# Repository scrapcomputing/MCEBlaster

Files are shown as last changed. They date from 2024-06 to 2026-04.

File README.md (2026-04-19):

# MCE Blaster

A versatile standalone MCA/CGA/EGA TTL to VGA adapter based on a raspberry pi Pico.

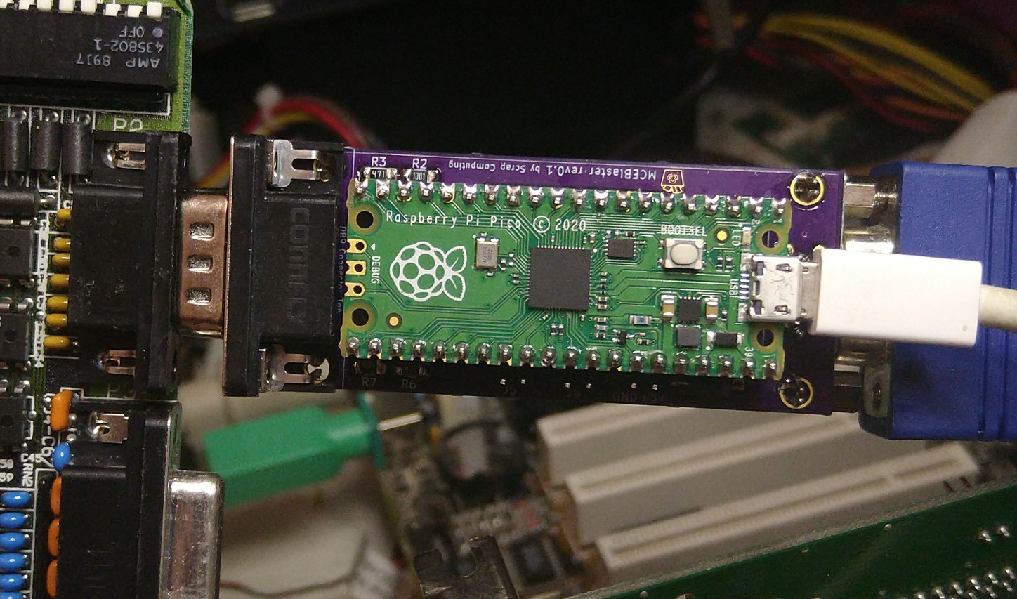
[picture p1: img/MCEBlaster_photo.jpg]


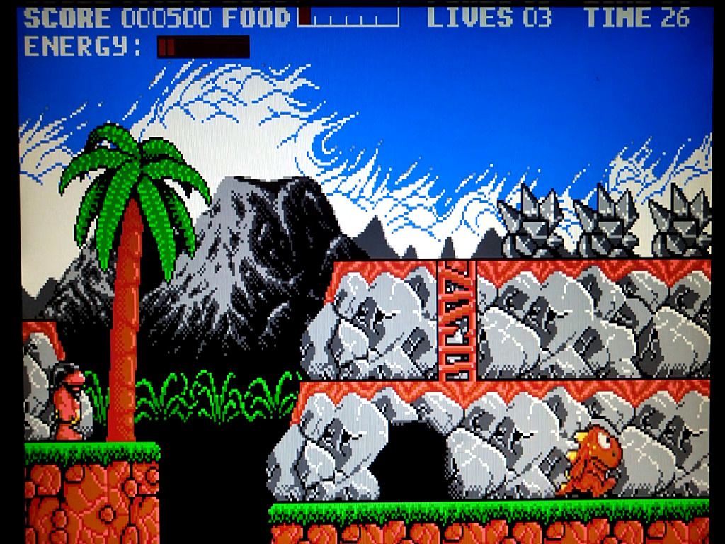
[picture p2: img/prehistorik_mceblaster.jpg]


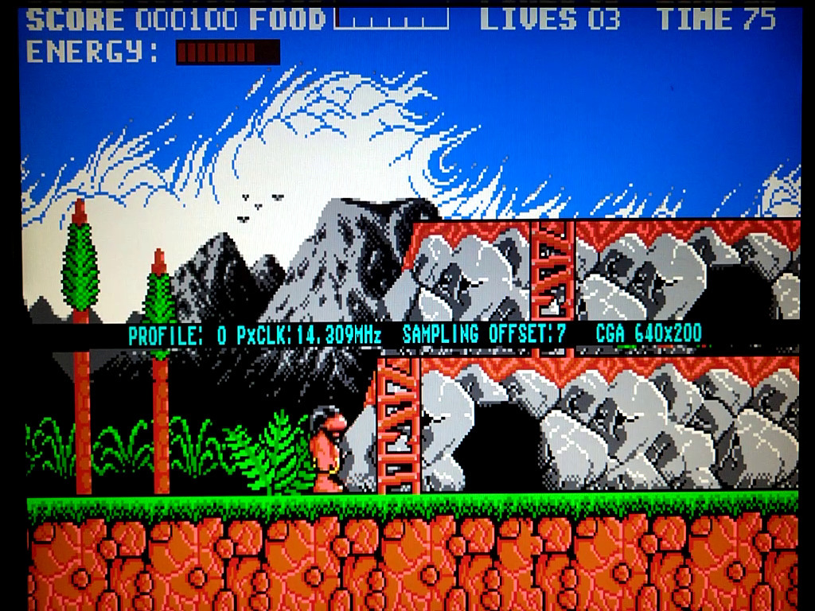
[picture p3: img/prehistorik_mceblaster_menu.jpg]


# Videos
- MCE Blaster video part 3: https://www.youtube.com/watch?v=SX1B-mfE6yk
- MCE Blaster video part 2: https://www.youtube.com/watch?v=Neg1WR7Hz5s
- MCE Blaster video part 1: https://www.youtube.com/watch?v=kgDOiGoxKvE

# What it does
The Pico reads the TTL input video signal, writes the pixels to a buffer and then generates the VGA signal using the pixels from the buffer.

# Features
- No need for a VGA up-scaler or a 15KHz VGA monitor. Works with standard VGA modes.
- Pixel-perfect output:
  - VGA 640x400 for CGA/EGA 320x200,640x200 and 640x350 inputs
  - VGA 800x600 for MDA 720x350
  - VGA 640x480 for vertical resolutions between 200 and 240
- Pixel clock tuning for each mode
- Auto-adjustment functionality that centers the image on screen
- EGA brown color correction
- On-screen menu and messages
- Through-Hole PCB

# Installing the firmware to the Pico (Pico 1 or Pico 2)
- Download firmware (MCEBlaster_pico1.uf2 or MCEBlaster_pico2.uf2): https://github.com/scrapcomputing/MCEBlaster/releases
- Unplug the Pico
- Press and hold the small "BOOTSEL" button on the Pico
- While holding the BOOTSEL button, connect the Pico to your PC with a micro-USB cable
- The Pico should show up as a mass-storage device
- Copy the `MCEBlaster_pico1.uf2` or `MCEBlaster_pico2.uf2` firmware to the drive associated with the Pico
- Safely eject the mass-storage device

# Usage

*NOTE: Controls have changed since version 0.2!*

## Adjusting the pixel clock
- Push the `PIXEL CLOCK` button once, this will enter the pixel adjust mode. This should show text on screen displaying the current pixel clock.
- Coarse adjustment:
  - Push `PIXEL CLOCK` to increment the pixel clock by 10KHz.
  - Push `AUTO ADJUST` to decrement the pixel clock by 10KHz.
- Fine adjustment:
  - Long-push (push until the push registers) `PIXEL CLOCK` to increment the pixel clock by 1 KHz.
  - Long-push (push until the push registers) `AUTO ADJUST` to decrement the pixel clock by 1 KHz.
  - Medium-push (about half a second push and release) `PIXEL CLOCK` to increment the sampling offset and then increment the pixel clock by 1 KHz once we have tried all offsets.
  - Medium-push (about half a second push and release) `AUTO ADJUST` to decrement the sampling offset and then decrement the pixel clock by 1 KHz once we have tried all offsets.
- Exit pixel clock adjust mode by not pushing any buttons for 12 seconds. This saves the settings to flash.

### Sampling Offset (since rev 0.3)
The sampling offset is a fine-tuning knob added in rev 0.3 that shifts TTL sampling to try to avoid sampling the pixels during the transitions (shown as `X`).
In this example, using a sampling offset of 1 will result in a very noisy image because sampling takes place during the pixel transitions.

```
                    _____ _____ _____ _____
TTL Pixels:        X_____X_____X_____X_____X
Sampling offset 0:      |     |     |     |
Sampling offset 1:       |     |     |     |
Sampling offset 2:        |     |     |     |
Sampling offset 3:         |     |     |     |

```

The reason why offsets are needed and a demonstration of how they work can be found in [video part 3](https://www.youtube.com/watch?v=SX1B-mfE6yk).

## Centering the image
- Push the `AUTO ADJUST` button. This works best when the image shown is full from border to border.

## Print TTL Info (since v0.2)
Long-pressing the `PIXEL CLOCK` button will show a screen with information about the TTL signal.
Note: this is not updated in real-time.

You can exit the screen by pushing any button.

## Manually Setting TTL Options (since v0.2)
By default the MCE Blaster will automatically detect the TTL mode by checking the VSync frequency and the VSync Polarity. If these match the standard MDA/CGA/EGA modes used in PCs this will usually work fine.

But since Version 0.2 the MCE Blaster also supports manually setting:
1. The mode (MDA/CGA/EGA),
2. The horizontal and vertical resolution
3. The horizontal and vertical screen offset (on the TTL side)
with the help of an on-screen menu.

The operation is straight forward:
- To enter the menu long-push both buttons for more than a second until the "MANUAL-TTL" menu shows up.
- The single-line menu consists of 4 items that can be modified. The one that can be currently modified is enclosed in square brackets `[<selected>]`. For example:
```
          Currently
          Selected      Horiz Offset  Vertical Offset
            vvv               vvv      vvv
MANUAL-TTL [CGA] 640 x 200 X: AUTO  Y: AUTO
   ^         ^   ^     ^
On/Off  TTL-mode Horiz x Vertical Resolution
```
the currently selected option is `CGA`.
- Change the value of the selected item with a short push of the buttons.
- Cycle through the items by long-pushing the buttons: one will cycle in one direction and the other in the opposite.
- The options are saved to flash when the user stops pushing buttons for 12 seconds.

## Reset to Factory Defaults (since v0.2)
Occasionally the user may save to flash some configuration that makes the MCE Blaster unusable or inoperable.
In this case you can reset to defaults by pressing both buttons while powering on the device.
Upon a successful reset you will see the LED blinking fast for about 2 seconds.
You can release the buttons after that and the MCE Blaster will start with the default settings.

## Profiles (since v0.3 beta13)
The MCE Blaster supports a number of profiles, which helps when swapping video cards.
The settings for one card can be at Profile 0, the settings for another card can be at Profile 1 etc.
The default profile is Profile 0.

Changing profiles is as easy as long-pressing the `AUTO ADJUST` button and cycling through the profiles with either the `AUTO ADJUST` or the `PIXEL CLOCK` button.

Profiles are demonstrated briefly in [video part 3](https://www.youtube.com/watch?v=SX1B-mfE6yk).

# How it works
## Overview
The first core reads the TTL video data (through the level-shifter) from a PIO state-machine and places the pixels onto a buffer in memory.
The second core works completely independently from the first core and reads the pixel from the buffer and feeds them, along with the necessary Horizontal and Vertical Sync signals to a PIO state machine that writes to GPIO outputs.
The output is converted to analogue with the help of a simple R-2R DAC consisting of two resistors.
Feel free to check out the [video part 1](https://www.youtube.com/watch?v=kgDOiGoxKvE) for a visual overview.

## PIO state machines
The PIO state machines are used not only receiving the TTL video data and writing the VGA video data, but also for other helper functions including:
- Detecting no input signal: This checks if the horizontal sync signal is active.
- Detecting the image offset: This counts the black border pixel until a non-black pixel is found across all lines. This count is used for centering the image automatically.
- The EGA PIO state machine also does the Brown pixel fix because the overhead of doing that in a CPU core was too high.

## Sampling clock
The TTL video input is read by a PIO state-machine (one version for each video mode).
But getting it to sample the pixels at the right time requires us adjust the sampling period in a precise way to match the TTL video card's internal pixel clock.
Using the PIO clock divider does not give us a good-enough precision, because the fractional part of the divider is an 8-bit number, meaning that we get precision of ~0.004ns, but what we really need is about 0.001ns.
So what we do is that we have multiple implementations of the state-machine code, each with a different sampling period and we look for the one that has the lowest division error using the PIO's 8-bit divider.
This process is explained in more detail in the [video part 2](https://www.youtube.com/watch?v=Neg1WR7Hz5s).

# PCB
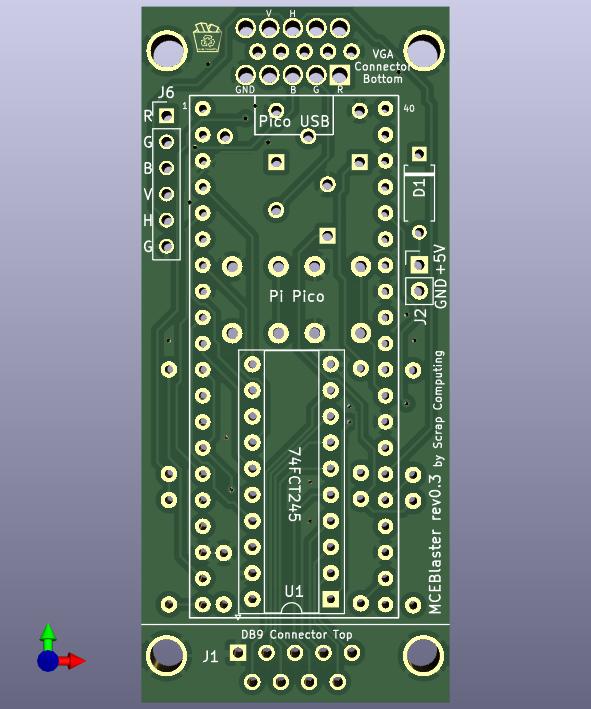
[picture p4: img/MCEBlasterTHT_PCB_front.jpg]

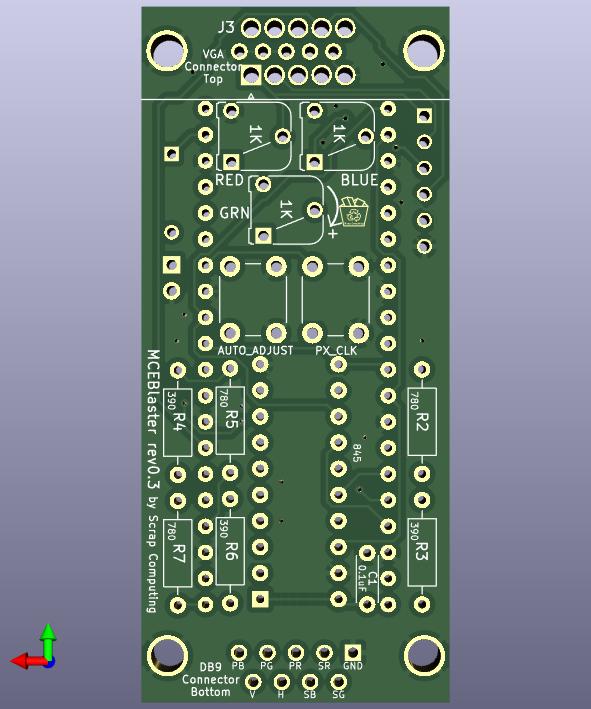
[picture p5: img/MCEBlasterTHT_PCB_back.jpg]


# Schematic

MCE Blaster Schematic

# Bill Of Materials

Download gerbers: https://github.com/scrapcomputing/MCEBlaster/releases

*NOTE: You can still use the latest firmware with old revisions of the PCB, they are fully compatible.*

Reference      | Quantity     | Value                                                                  | Description
---------------|--------------|------------------------------------------------------------------------|------------
N/A            | 3            | 1K Rm065 through-hole linear potentiometer (optional: can be replaced by a wire between 2 pins as shown on PCB and the [photo below](#potentiometers-are-optional) | Adjust R G B VGA signals
C1             | 1            | 0.1uF disk ceramic capacitor                                           | Decoupling capacitor for level-shifter IC
D1             | 1 (optional) | Diode Through-hole (e.g., Schottky 1N5817 or silicon 1N4001)           | For powering the MCE Blaster from the PC (instead of the Pico's micro-USB)
J2             | 1 (optional) | 1x02 through-hole Male PinHeader 2.54mm                                | For alternative external power
J1             | 1            | DB9 Male Horizontal                                                    | For connecting to TTL video card
J3             | 1            | DB15 Female HighDensity Connector (e.g., Kycon K61X-E15S-NJ-VESA, thanks @wrljet) | For connecting to VGA monitor
R3 R4 R6       | 3            | 390 Ohm Through-hole resistor 1% (alternatively 470 Ohm)               | For VGA signal DAC
R2 R5 R7       | 3            | 780 Ohm Through-hole resistor 1% (alternatively 1K Ohm)                | For VGA signal DAC
SW1,SW2        | 2            | 6mm Through-hole push button                                           | Auto-adjust and pixel-clock buttons
U1             | 1            | 74LVC245A DIP-20 (e.g., SN74LVC245AN) (+ optional socket)              | Level-shifter IC (NOTE: in the video I am using an 74HCT245 which turns out operates [out of spec](https://github.com/scrapcomputing/MCEBlaster/issues/31))
U2             | 1            | RaspberryPi Pico (or Pico 2)                                           | Pi Pico (or Pico 2)
N/A (for Pico) | 2            | 1x20 female through-hole pin-header 2.54mm pitch                       | PCB Pico headers
N/A (for Pico) | 2            | 1x20 male through-hole pin-header 2.54mm pitch                         | Headers for the Pico

## Potentiometers are optional.

They can be replaced by a wire as shown in the photo:

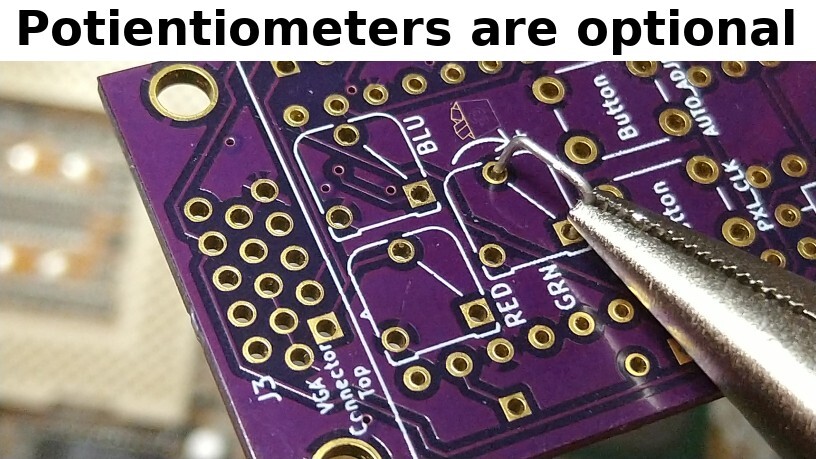
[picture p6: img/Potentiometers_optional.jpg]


# Build instructions (for developers)
## Requirements:
- C++17 cross compiler (see instructions in https://github.com/raspberrypi/pico-sdk)
- Pico-SDK 2.2.0 or later (https://github.com/raspberrypi/pico-sdk)
- cmake 3.13 or later

## Build for Pico (rp2040) or Pico 2 (rp2350)
```
$ cd firmware && mkdir build && cd build
$ cmake -DPICO_BOARD=<pico|pico2> -DCMAKE_BUILD_TYPE=Release -DPICO_FREQ=270000 -DPICO_SDK_PATH=<path-to-pico-sdk> ../src/
$ make -j
```

# Resources:
- https://minuszerodegrees.net/mda_cga_ega/mda_cga_ega.htm
- https://en.wikipedia.org/wiki/IBM_Monochrome_Display_Adapter
- https://en.wikipedia.org/wiki/Enhanced_Graphics_Adapter
- https://en.wikipedia.org/wiki/Color_Graphics_Adapter
- https://en.wikipedia.org/wiki/VGA_connector

# Similar Projects
- Necroware's [mce-adapter](https://github.com/necroware/mce-adapter)
- [RGBtoHDMI](https://github.com/hoglet67/RGBtoHDMI/wiki)

# Change Log
- Rev 0.1: Initial release.
- Rev 0.2: Major redesign. Manual TTL, menus show live background
- Rev 0.3: Better adjustment of pixel clock with sampling offset, support for Pico 2, and fix colors in some monitors

# License
The project is GPLv2.

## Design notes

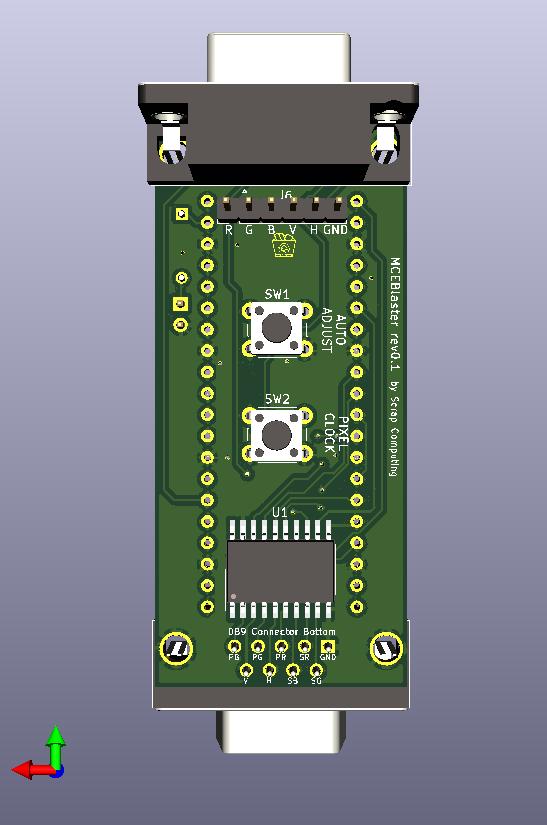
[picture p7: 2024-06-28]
img/MCEBlaster_PCB_back.jpg

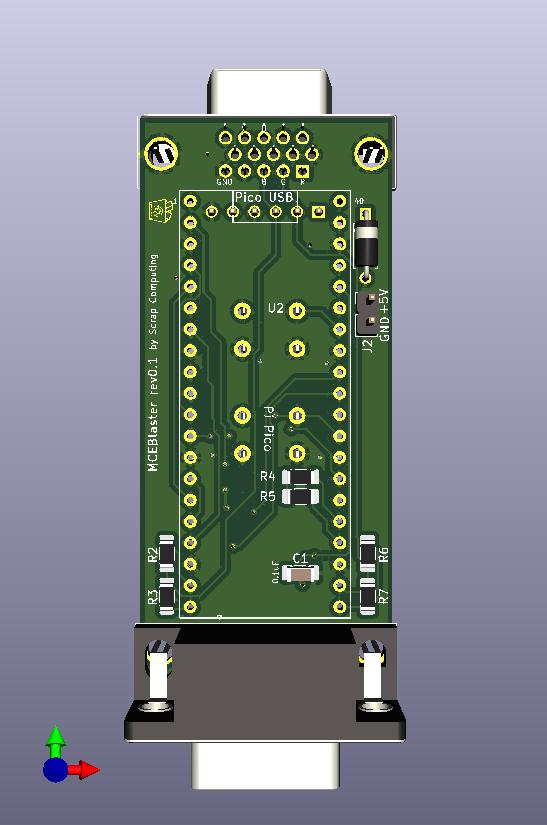
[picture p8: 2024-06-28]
img/MCEBlaster_PCB_front.jpg

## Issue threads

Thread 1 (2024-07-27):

cant find email so I upload boardview for ASUS P5A-B in one of your github projects :) its almost same board, just AT form factor

raszpl, 2024-07-27:
cant find email, uploading here  https://www.youtube.com/watch?v=MigVZLc_Mgw
[ASUS P5a-b_1.05.7z.zip](https://github.com/user-attachments/files/16401720/ASUS.P5a-b_1.05.7z.zip)

HIP is in upper right corner U15, SS controlled by Q11 'VCC2DET'. this signal also goes near the W83781G to either:
-74 series logic chips
-ASUS "Asic"

Asus AS something something 256 is afaik just a bunch of logic gates
EDIT: my own vogons post: https://www.vogons.org/viewtopic.php?p=1120994#p1120994

scrapcomputing, 2024-07-27:
Thanks!

ImprovedTube, 2024-07-29:
you good? @raszpl  will give all my retro computing parts for youtube extension fixes.

Closed 2024-07-27.

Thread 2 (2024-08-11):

Add mode for Apricot XI PC

stevenhoefel, 2024-08-11:
The Apricot XI PC provides an MDA-like display with 800x200 pixels at 15.798khz H and 71.9 V.
I've managed to compile and build the project. I then attempted to manipulate the existing MDA mode to these settings, but I can't stop the Pico from freezing up. I also don't have a proper debugging setup and using USB serial isn't a good method.

Any chance you could provide some guidance on how to add this archaic display mode?

Thank you!

stevenhoefel, 2024-08-11:
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

scrapcomputing, 2024-08-11:
Hi,

For the 800x200 monochrome mode I would change the MDA_720x350@50 entry in TimingsVGA.h (at least for now). Make sure the `F`, `Vis` and `B` fields are multiples of 4, otherwise the Pico will freeze.

From the figure you posted above, I guess the pixel clock is 15MHz, and H sync polarity is positive and V sync polarity is negative.

Something like this may be a good start, though I have not adjusted the porch sizes (please do so if needed and remember they should be multiples of 4, though I don't think they are super critical):
` {16, 800+XB, 20,   126, 20, 200,  4, 16,  Pos,  Neg, 15798, 50, 15000000, 1},`

I think that updating this line shouldn't cause the Pico to freeze and should display something.

Oh btw, don't change the DisplayBuffer's `Buffer` dimensions, 800 monochrome should fit fine, as we are storing 2 pixels per byte horizontally. If you increase the size, the Pico will run out of memory and will freeze.

Debugging is tricky but can be done via USB. You can use `-DDBGPRINT=on` in cmake which turns on some basic debugging. If you have configured the `TimingsVGA.h` correctly then you should be seeing messages like "Updating Buff.Mode=" that match your modified MDA mode.
Otherwise you may be seeing messages like "Could not match Polarity"

 The issue is that printing things via USB can mess up with the timings and you get a noisy image on the VGA, but works all right as long as you don't print too often. I usually print stuff in TTLReader.cpp in `runForEver()`, see commented out lines towards the bottom.

After you get it to show things, you may need some vertical pixel doubling, like in 640x200 EGA mode, similarly to how it's done in VGAWriter.cpp: `DrawLineVSyncHigh4x1(Line/2)` instead of `Line`.

I hope this helps, feel free to reach out again if you run into issues.

stevenhoefel, 2024-08-11:
After a lot of tinkering, the best I could produce was a pretty-good image hanging off the top-right of the screen.

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

It wouldn't work by amending the MDA line... instead I had to amend the EGA 640x200 which makes me think there's other calculations going on for MDA that don't apply to EGA. The line that produced an image was:

  /*EGA_640x200@60:*/ {36,  720+XB, 20,   56, 32,  200, 56, 16,  Pos,  Pos, 15798, 72, 15798000, 1},

Note the 72hz for the Vertical Frequency and Positive V Sync. Otherwise the code reported no matching configuration.
From here, should I just adjust the borders/offers to center this EGA picture? Or should I work harder to get the MDA method to match?

I'll tinker more again tomorrow and review how the code paths for MDA and EGA differ...

Attempting to use the row above in the MDA slot just causes a clear black screen with no image data present at all.

scrapcomputing, 2024-08-11:
Ah nice, you got some image :D

Well the buffer for EGA/CGA is only 640 pixels wide, so it won't fit 800 pixels unless you make the buffer wider but shorter, but in that case you won't be able to switch to EGA/CGA. This is why I would try to modify the MDA mode instead of using EGA/CGA. Also you would have to wire it carefully to get the intensity working.

Hmm are you using the project's wiring? If not, then this is probably why MDA is not working. MDA is using different GPIOs. It's using GP6 to GP9 for V, H, INT, PB (see the schematic), while CGA/EGA is using GP0 to GP7.

stevenhoefel, 2024-08-11:
I've soldered/wired everything together on a prototype schematic, wiring all same-named pins between the 74LVC245 and the Pico together. I've been checking what you've mentioned with GP6-9, but that doesn't line up with the schematic?

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

I had initially assumed that my monitor would need its 'video' wired into all R/G/B to get a white colour. This would also cause the right signals through to GP6 - 9. So I had wired it as follows:

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

I can see how this makes the unit think that an EGA signal is coming in as there's data on all. Tongiht I'll reduce that wiring and only feed video in on TTL_PB with ground for intensity and see if I can get MDA working.

scrapcomputing, 2024-08-12:
Sorry, I was wrong. Common.h lists the GPIOs used by each mode:
EGA: GP0-5: BBGGRR GP6:V GP7: H
CGA: GP8-13: BBGGRR GP6:V GP7: H
MDA: GP26: Intensity GP27: Video

stevenhoefel, 2024-08-12:
After a lot of tinkering, I have a horizontally-centered vertically-squished picture! I had to lower the pixel clock quite a bit to get the full set of pixels for each row to display. I also had to lower the count to 720 pixel visibles? I must admit there is too much guesswork involved on my side.

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

The currently-configured row for MDA is:

  /*MDA_720x350@50:*/ {16, 720+XB, 20,   126, 20, 200,  4, 16,  Pos,  Pos, 15798, 72, 13018181, 1},

I also had to set the XBorderInit to 0 to get the picture off the edge of the screen. Finally, any hints on stretching the picture vertically? I would be happy with just a doubling of each row of pixels!

scrapcomputing, 2024-08-13:
Pixel doubling is easy, you just need to use `Line/2` just like in VGAWriter.cpp:230

This is strange. Lower pixel clock should make the image wider.
But with a lower pixel clock you would indeed need a shorter H_Visible, otherwise `readLineMDA` would be waiting for more pixels to arrive and would loose synchronization with the PIO that provides the data (see `if (PixelX > XMaxPixelX) { break; }`).

The way it works is that TTL is read by `Pio/MDA720x350_*.pio`. This reads the pixels at the specified pixel clock and pushes them into the queue for `readLineMDA()` to received them on the host side (`uint32_t MDA8 = pio_sm_get_blocking(...)`). The pio will break out of the data loop if it detects a positive HSync, and wait there pushing zero values until the new line. In the meantime the host is counting pixels with the `BuffX` counter and checks against `Timing[MDA_720x350_50Hz][H_Visible]`, and will break out of the loop if it thinks that it has received the whole line. So both H_Visible and the pixel clock of the Pio must be fairly close to the correct value, otherwise you can get weird race conditions.

Btw you have overclocked the Pico haven't you? I would only get a stable image with `cmake -DPICO_FREQ=270000`.

stevenhoefel, 2024-08-15:
Apologies for the delayed response as there's been a lot of tinkering on this side to get the image displayed. Indeed the Pico is overclocked to 270000 as per the make command in your CMakeLists.txt.

Going back to the specs in the first image in this post, I attempted to get the full 800x400 (80x25 chars at 10x16 per char) displayed which meant a vertical resolution of 400 pixels. Of course, as you mentioned, this wouldn't fit in the Pico RAM with the 640px width, so I shrunk that to 400 as we're storing 2px per byte.

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

This worked, but then it became apparent that I'm reading two input lines at once and overlapping them? Doing the "Line / 2" in VGAWriter stretched this out, but that can't be the right answer as I assume the image (once I have an input device and can display a full proper image that covers 100% of the display) will only show half.

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

I'm currently waiting on parts for the keyboard interface, so I'll update when I tinker more!

scrapcomputing, 2024-08-24:
The image looks very fuzzy, which could mean that the pixel clock is not correct.

I doubt that pixel doubling is the issue, it should produce pixel-perfect output. The only distortion you should be getting is from the LCD monitor's scaler.

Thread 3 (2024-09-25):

Save auto-adjust position?

SanguineBrah, 2024-09-25:
Thanks for this project, we have been dying for a cheap solution to this problem for a long time.

Whenever I turn on my computer, the MCEBlaster cuts off the top row of text. I can fix this by opening a full screen program and pressing auto-adjust but it would be great if we could save the starting adjustment to flash memory so it is immediately correct on boot. This would make it more practical to mount the MCEBlaster internally.

scrapcomputing, 2024-09-26:
This might work, I will give it a try, I will save the position for each mode. The only issue that I can think of is that you may still need to adjust the image when launching different programs, because they can still mess up with the position.

scrapcomputing, 2024-10-10:
I think I implemented the feature: Whenever auto-adjust runs it saves the values to flash (for each mode) and should use the flash values from that point on.
Could you try out the attached firmware and let me know if you run into any issues ?
(unzip before copying to Pico).

Thanks!
[MCEBlaster.uf2.zip](https://github.com/user-attachments/files/17322472/MCEBlaster.uf2.zip)

SanguineBrah, 2024-10-10:
I can only test with CGA but that is working well for me. I can now turn on my computer and have the image correctly positioned right from the BIOS. I haven't noticed any unforeseen side-effects at all.

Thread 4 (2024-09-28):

Power header suggestion

SanguineBrah, 2024-09-28:
If you ever decide to make another revision of the PCBs, I would recommend using something like a Molex KK or floppy-style berg header footprint for powering the board. This should make it difficult to plug the power in backwards by mistake.

scrapcomputing, 2024-10-06:
Yeah, the floppy-style connector would be ideal. Do you happen to know of any part numbers for it?

SanguineBrah, 2024-10-06:
The straight header is TE Connectivity AMP Connectors 171825-4 and the right angle version is 171826-4. They are a little strange because the pin spacing is 2.5mm instead of the usual 2.54mm (0.1'').

scrapcomputing, 2024-10-06:
Thanks!

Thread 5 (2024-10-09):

new suggestions

emilen72, 2024-10-09:
Hi, very glad to see that great work!!!

I think that is even good for add vga output to all retrocomputer 8 bit with TTL rgb output 15khz (a sort of cga) and even console as Intellivision and Videopac and more :-)

What do you think about the idea of   using the clone purple versione of the pico? It's used a lot this days on many 8 bit related multicart because it has same number of pin but more gpio pin available, it has 16mb flash on board, it's 5v tolerant (no need of level shifter) it cost same as pico... the flash memory could be used to store many sync profile and resumed on demand to user. Ok I'm not a programmer, so free to tell me id I'm only a dreamer :-)

regards
Emiliano

for references
https://forums.raspberrypi.com/viewtopic.php?t=337976
https://github.com/aotta/PiRTOII
https://github.com/robinhedwards/A8PicoCart
https://oshwlab.com/yannick.erb/Intellivision-Secam-RH-RGB-Mod_copy_copy

scrapcomputing, 2024-10-10:
Thanks for reaching out.

Not sure how well it would work with RGB TTL, haven't looked into the spec. It may require some tweaks.

Regarding the purple Pico, I prefer working with the original one because it's the official product and it will be widely available for many years in the future. Not sure about the 5V tolerant claim, I don't see any level shifters on the board. Some people claim that the Pico itself is 5V tolerant, but it's certainly not rated as such.

What I am really excited about is the new Pico 2, which is a great fit for this project as it addresses the performance and RAM issues. I will work on a new version of this project once I get my hands on one :)

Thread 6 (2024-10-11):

Output too 'hot'?

SanguineBrah, 2024-10-11:
I'm not sure if this is just a problem with my build. I could source resistors that were quite close to the values on the BoM but not exactly right (820ohms and 430ohms). On my oscilliscope I can see that the RGB outputs are at about 1v p-p, which is 0.3v too high for spec. I with try with the alternate values of 1k and 470 to see if that helps.

In terms of symptoms, some of my monitors go through AGC adjustment then stabilise with a good image but some show distorted colours when the intensity bit is used.

SanguineBrah, 2024-10-11:
Luckily, I am a terrible hoarder so I have many old VGA monitors to test with!

All of the monitors I tested showed about 78/79ohms on the RGB lines, which includes the cable so this is probably very close to 75 in reality. On the scope, all of them showed RGB hitting up to 1v p-p at the cga_comp colour bars test.

The following three monitors worked perfectly, with no unusual behaviour:
Dell E176FPm
NEC Multisync LCD1770NX
Samsung 2043BW

This one is an LCD TV, which worked but could be seen to be making AGC adjustments whenever the picture changed:
JVC LT24C660(D)

This one showed major colour issues wherever the intensity bit was used:
HP L1910

This lines up with what I have read, which is that 1v VGA signals are supported by some monitors but that it is inconsistent.

scrapcomputing, 2024-10-12:
I checked my adapter, and I am actually using 1K and 470 resistors instead of the "theoretically optimal" 845/422 ohm ones. And I can see some spikes at ~680mV.

The formula for calculating the optimal resistor is `5.571 * RGBresistance`, so for RGBresistance 75 Ohms, `R = 418 Ohms`.
But if the RGBresistance is a bit higher, say 80 Ohms, then the `R = 446`.
So a 470 / 1K resistor pair is probably a safer choice.

SanguineBrah, 2024-10-12:
I have changed over to the 470/1k now, which brought the levels down close to 700mv, although my scope sometimes measures 800vm due to noise and over/undershoot. However, after some more testing, this symptom seems to be quite a bit stranger than I thought and it is not caused by the intensity of the signal. This is the cga_comp's colour bar test on the HP monitor (IBM CGA card):

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

It looks perfect. No colour issues with any of the colours. Now this is the RGB intensity test:

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

The left bar should be bright red, and the right bar should be white. For comparison, this is the same HP monitor plugged into the 31khz port of my Morse KP 800/16:

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

Here is the same symptom at the EDIT screen:

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

Another thing I noticed was that the first column of text looks darker than everything else:

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

It looks the same at the DOS prompt (the C in C:\ is darker.

scrapcomputing, 2024-10-12:
Thanks for the detailed bug report!

Bright Cyan RGB is #55FFFF and White is #FFFFFF, so if you are seeing cyan instead of white it means that red (rR) is 10 instead of 11. The red bar should be (rR) 01 but it's showing as 00, so both are showing one level lower.

I wonder if this is related to the brown-color fix (which lowers the green signal by one level) but applied to red instead of green for some reason. Have you tried power-cycling the Pico while running this test?

Regarding the first column showing darker, I suspect this is a VGA sync issue that has to do with the signals being slightly off, in an attempt to avoid black bars on the sides of the screen.

I will try to reproduce both issues locally so I can investigate further.

SanguineBrah, 2024-10-12:
Power cycling the Pico doesn't change the behaviour. The RGB intensity test shows correctly when I test with my other monitors, so I think it is more likely to be some feature of the output VGA signal that this monitor can't tolerate. It is difficult to see from my photos but on both of the faulty example screens (the EDIT screen and the RGB intensity test), the colour is correct at the very top of the screen and then it very quickly fades to a different colour (red -> dark red, white/cyan).

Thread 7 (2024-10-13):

Support for Heidenhain TNC 150 mill to replace BE110B CRT

Perklo, 2024-10-13:
Hi,

First, thank you for sharing this great RP2040 project. It's an inspiring example of the capabilities of PIO state machines, I've really enjoyed exploring it when looking for a video converter for my need.

The MCE Blaster is nearly working "out of the box" for my need. I get good a picture but 80% of the width, so it requires some adaptation.

I've identified the following video signal characteristics, measured with an oscilloscope. Pictures below.

- 4 logic level signals: Vsync (positive), Hsync (positive), Pixel, Intensity
- Frame rate: 48.9 Hz
- Line frequency: 15.2 kHz
- Pixel frequency: 5.1 MHz (unable to find shorter pixel pulses)
- Approximately 311 lines and 336 pixel columns, suggesting about a 300 x 300 image.

Based on this, the timings could be something like the following:
----------------------F Vis   B Sync  F Vis   B  Sync  HSync VSync H_Hz V_Hz PxClk      TTL 
 TNC_300x300@50:  --, 300+XB, --,  --,  --, 300,  --,  --,  Pos,     Pos, 15239, 49,     5120304, 1

When I feed the signals directly into the MCE Blaster, it doesn’t auto-detect any video signal. However, inverting the Vsync results in detection as an MDA 720x350 @ 50Hz. I believe the pixel clock is then set to 15 MHz, and the MCE Blaster is reading one pixel column three times. To capture a 300-pixel line like this would require a 900 pixels buffer, but the system halts after reading 720 pixels, leaving 60 pixels (about 20%) uncaptured.

I think I would manage to fix this in the code but I'm currently struggling to set up the build environment and would appreciate any guidance to help me. I’d be happy to contribute to the project, particularly in adding support for this application, but I could use some assistance to get unstuck.

Could you provide some details about your development toolchains and versions? Additionally, would it be possible to add support for the above signal in a new revision? While I’m open to attempting this myself, I think if you do it could speed up the process significantly.

---

### Background:

I’m aiming to use the MCH Blaster as an adapter to enable any monitor to work with a vintage Heidenhain mill control system. A friend of mine has an older CNC mill (Heidenhain TNC 150), and the original CRT monitor (Heidenhain  BE110B) has failed. An adapter like this would provide a cost-effective solution to make it operational again.

I believe the video signals used by Heidenhain are proprietary and don't follow the common standards evolving during the 1980s. I’m still learning about video signal history, so I may be missing something here.

---

### Additional Info:

I’m having some difficulties setting up the firmware to build, mainly due to my limited experience with CMake and the toolchain setup. I’m using VSCode on Windows and have worked with the RP2040 using both the RP2040 Raspberry Pi Pico VSCode extension and the Arduino-Pico package https://arduino-pico.readthedocs.io/en/latest/ . However, I’ve struggled to create a build environment that builds the code, encountering numerous compilation errors—possibly due to conflicts with my existing toolchain versions.

Any assistance or guidance would be greatly appreciated!

Thanks again for creating and sharing this project.

Best regards,
**Per**

Frame  signals. ch1 Vsync (inverted), ch2 Hsync, ch3 Pixel, ch4 Intensity
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
80 % MCE Blaster capture
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
MCE Blaster detecting MDA
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
Frame frequency 48.9 Hz
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
Line frquency 15.2 kHz.
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
Line signals
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
Pixel 5 Mhz and intensity
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
15 higlighted lines mid screen
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

scrapcomputing, 2024-10-13:
Thank you for the detailed information.

I am building the project on a fairly standard Linux system using the following commands, replacing `/path/to/pico-sdk` with the directory where you downloaded the pico-sdk (which can be found here: https://github.com/raspberrypi/pico-sdk - it lists its dependencies).

```
cd MCEBlaster/firmware/src
mkdir build && cd build
cmake -DCMAKE_BUILD_TYPE=Release -DPICO_FREQ=270000 -DPICO_SDK_PATH=/path/to/pico-sdk/ ../src/
make -j
```
Adding `-DDBGPRINT=on` will also enable some debug messages through the USB interface, which you could read with a terminal emulator.

Not sure how/whether it will build on Windows with VSCode.

Regarding supporting the 5MHz pixel clock, I would just modify the `MDA_720x350@50` configuration line in `TimingsVGA.h` with the settings you suggested. I am not sure whether there will be any more issues, because the Pio  or mode detection code (in `getModeForVPolarityAndHz()`) may need to be adjusted, but at least this looks like a good starting point.

I made this one-line change and have attached the zipped firmware, please give it a try.

```
  /*MDA_720x350@50:*/ {16, 300+XB, 20,   126, 20, 300,  4, 16,  Pos,  Pos, 18430, 50, 16257000, 1},
```
[MCEBlaster_Mil.uf2.zip](https://github.com/user-attachments/files/17356312/MCEBlaster_Mil.uf2.zip)

Perklo, 2024-10-13:
Thanks for your quick answer, and preparing a test firmware. I did look to be close with only a multiple rate diff on the clock, so I would not be surprised if it work. Given that the auto detect gets it. It should be a better chance than catching a rocket mid air i assume, and that worked ok..
It will be a couple of weeks until i am at my friends place and in the shop with the mill. I will get back with any observations.
Thanks for confirming that you are on Linux. And for your cmake/make switches used, I will try to build it without the overhead of the vscode overhead. I might as well just set up a Linux system I guess..
Cheers,

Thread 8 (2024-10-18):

help with pico usb-c version

emilen72, 2024-10-18:
Hi,
Is there any reason why the build doesn't work with USB-C Pico? Have you any experiences?

I have some Aliex picos... some with micro-usb and some with usb-c.

the USB-C version doesn't like this build. the pico usb-c version is working and is ok with other designs like Apple2VGA ( and Apple2VGA also works with the micro-USB version).

the pico micro-usb version instead is ok...

the usb-c and micro-usb version have same chip and same pinout.

Any ideas?

scrapcomputing, 2024-10-19:
Sorry, I've never tried the usb-c ones. But if I where to guess, perhaps it doesn't work at 270MHz for some reason?

emilen72, 2024-10-21:
Reading on the net, I think is due to a slow flash chip used on many pi pcio, other project noted this and fix it adding code to CMakeLists or define custom board.

i.e.
https://github.com/robinhedwards/A8PicoCart/tree/main/source/Pico%20VSCode%20Project/a8_pico_cart
for fix it defines a custom board with a higher value for PICO_FLASH_SPI_CLKDIV so it supports the slower flash.

// myboard.h
// setting first overrides the value in the default header
//#define PICO_FLASH_SPI_CLKDIV 2     // use for winbond flash
#define PICO_FLASH_SPI_CLKDIV 4     // use for slower flash (e.g. zbit)
// pick up the rest of the settings
#include "boards/pico.h"

or in https://forums.raspberrypi.com/viewtopic.php?t=301902 they suggest this way

[Re: Overclocking Pico with up to 270MHz works](https://forums.raspberrypi.com/viewtopic.php?t=301902#p1811232)
[Tue Feb 02, 2021 3:49 pm](https://forums.raspberrypi.com/viewtopic.php?p=1811232&sid=0555936b7910faf30de8f8c3f445444e#p1811232)

about about 270Mhz system clock you are probably out of range of the flash chip.

Do something like this in your CMakeLists.txt
Code: [Select all](https://forums.raspberrypi.com/viewtopic.php?t=301902#)

pico_define_boot_stage2(slower_boot2 ${PICO_DEFAULT_BOOT_STAGE2_FILE})
target_compile_definitions(slower_boot2 PRIVATE PICO_FLASH_SPI_CLKDIV=4)

pico_set_boot_stage2(TARGET slower_boot2)
to use a custom boot_stage2 which configures the flash slower (relative to system clock)

maybe this help to make the project more flexible

tnx

scrapcomputing, 2024-10-27:
Thank you for looking into this!
I have ordered a pico clone and I will try out your suggestions.
Thanks!

emilen72, 2024-10-28:
it works! with Pi Pico clone purple (even without buffer as many other projects). at moment I test only MDA

I mod the sdk for spiclkdiv for that

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

scrapcomputing, 2024-11-03:
Great, thanks for sharing!

scrapcomputing, 2024-11-09:
One more person reported a similar issue with an original Pico this time, and your solution fixed the issue :)
I patched CMakeLists.txt and it will build with the slow flash by default now. I have also added a new firmware in the releases (`MCEBlaster_rev0.1c.uf2`). Thanks for looking into this once again!

hitchhiker85, 2025-04-20:
hi you dont use the signalconverter// levelshifter??? i was thinking the pico need the levelshifter!?

scrapcomputing, 2025-04-20:
The Pico is not 5V tolerant, so you do need a level shifter for proper operation. But some people have reported that it doesn't get damaged if you don't use one, so it's up to you :)

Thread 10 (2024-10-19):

Support for Japanese PC-98 Machines

pocoaust, 2024-10-19:
Firstly, a BIG thank you for your work.

I have a NEC  APCIII with a 9 pin DB output.  It is wired as a 9 Pin NEC type output.  My Acorn 3000 has the same output.
the NEC has a V-freq of 56.4Hz and H-freq 24.8kHz  and resolution of 640x400.  It may run directly on my LCD that goes down
to 15khz, but I have not tested yet.  Ideally I would like to be able to run any VGA.

  "NEC standard"
   1,2,3  r,g,b luminance
    4,5   H and V sync
   6,7,8,9   all GROUND

Would this be supported.  I am waiting on thru holes PCB's and will do some testing when they arrive, but was wondering of the 640x400 resolution is a problem.

Thanks
Paul

scrapcomputing, 2024-10-19:
Hi,

Sadly I don't think it will work. There is no room for 640x400 in CGA/EGA mode because of the Pico's 256K memory. In theory it is possible to get it to fit in memory, since it's only using 3 bits for RGB. So we could pack 2 RGB pixels in 1 byte, just like it's done with MDA mode, but that would require different wiring, and I am not even sure that the Pico will be fast enough to handle it.

I think our best bet is to use a Pico 2 once it becomes available because it has twice as much memory. I am planning to port the firmware to the Pico 2 once I get my hands on one. Once that works, we could try to modify the firmware to support this NEC mode.

Thanks!

pocoaust, 2024-10-19:
I would like to assist in getting you the pico 2, as I believe this could help with many machines.  PM me on pocoaust@gmail.com.
Thanks

scrapcomputing, 2024-10-20:
Thanks for the kind offer, but don't worry about it. I just checked and they seem to be in stock in a couple of stores, so I will pick up a few soon.

pocoaust, 2024-10-20:
No probs, reach out if you need anything or testing etc with different
platforms, I have most.

On Sun, 20 Oct 2024, 11:42 am Scrap Computing, ***@***.***>
wrote:

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

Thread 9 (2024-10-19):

Thru Hole Boards

AusPuf, 2024-10-19:
I just assembled one and have found that the D Sub 9 is mounted on the wrong side of PCB as per the image thus no input signal flipped it around and it seems to work but with some issues, got find out if is a hardware problem

scrapcomputing, 2024-10-19:
I am not sure I follow. Did you place the connector on the wrong side, or is the PCB layout wrong?
What kind of issues are you having ?

AusPuf, 2024-10-19:
Seems the PCB layout is wrong had the boards made by PCBWay. I soldered the
D Sub 9 the way you have it in the image, I got no input signal error, so I
desoldered it and put it on the other side so now the pins match. ie. gnd
to gnd and pin 5 to pin 5. so now both D Subs are on the same side.

On Sat, Oct 19, 2024 at 9:57 AM Scrap Computing ***@***.***>
wrote:

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

scrapcomputing, 2024-10-19:
I checked the layout and the positioning of the DB9 connector looks correct to me. When looking at the back of the board (where the buttons are) GND should be the rightmost pin at the top row and the connector should be soldered at the back (as shown here: https://github.com/scrapcomputing/MCEBlaster/blob/main/img/MCEBlasterTHT_PCB_back.jpg?raw=true). Then the GND pin on the PCB should have continuity with pin 1 of the connector. So the marking "DB9 Connector Bottom" is the side where you do the soldering.

AusPuf, 2024-10-19:
When the D Sub is soldered as shown in your image, the gnd on the pcb is
then connected to pin 5 of D Sub. I've included images of the board and the
plug. The pic of the D Sub has pin 1 (gnd) on the right side

On Sat, Oct 19, 2024 at 11:42 AM Scrap Computing ***@***.***>
wrote:

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

scrapcomputing, 2024-10-19:
Ah I think I know what's wrong. You must be using a female DB9 connector. You should be using a male DB9 connector instead. On the male connector the GND pin on the PCB connects to pin 1.

By the way the images don't seem to have gone through.

AusPuf, 2024-10-19:
Your way no input signal i had to solder it on to the opposite side as in
the attached pic to get input signal.

On Sat, Oct 19, 2024 at 12:44 PM Scrap Computing ***@***.***>
wrote:

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

scrapcomputing, 2024-10-19:
Are you sure you are using a male DB9 connector ? Because on the Female connector the rightmost-pin connects to pin 1 not pin 5.

The images are not getting through, probably because you are sending them over email ?

AusPuf, 2024-10-19:
Ah me stupid I'm using a DB9 female no wonder i'm having issues So Sorry

Thankyou

On Sat, Oct 19, 2024 at 1:27 PM Scrap Computing ***@***.***>
wrote:

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

scrapcomputing, 2024-10-19:
No problem, let me know if you run into any more issues.

Closed 2024-10-19.

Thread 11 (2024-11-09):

Can't start the board!

Ruslan184, 2024-11-09:
Greetings! I made a board, flashed Pico, but nothing happens when connected to a PC. I soldered another board, but the result is the same. Any ideas why I can't get the board to work?
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

scrapcomputing, 2024-11-09:
It could be that the flash chip isn't fast enough to handle the overclocked frequency.
Could you try the attached firmware ?
[MCEBlaster_slowflash.uf2.zip](https://github.com/user-attachments/files/17689130/MCEBlaster_slowflash.uf2.zip)

Ruslan184, 2024-11-09:
Everything works! Thank you very much!
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
With the new firmware, the LED lights up when connected.

scrapcomputing, 2024-11-09:
That's great!
I have not tested this firmware much, so please let me know if you run into any issues. Thanks!

Ruslan184, 2024-11-17:
Ні! Can't center the image. Cropped on the left. Is it possible to fix it somehow? Monitor 17"
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

scrapcomputing, 2024-11-17:
1. What mode is this, is it MDA, EGA 640x350 or EGA 640x200 ?
2. Does this happen in all modes or applications?
3. I assume you have tried centering the image using the monitor's settings, but just to make sure you have already tried it.
4. Could you try the attached firmware to see if it fixes the issue.
[MCEBlaster_rev0.1c_XB0.uf2.zip](https://github.com/user-attachments/files/17791554/MCEBlaster_rev0.1c_XB0.uf2.zip)

Ruslan184, 2024-11-17:
EGA 640x200
With the new firmware, everything is the same.
I am trying to adjust the image on both the MCEBlaster and the monitor.
The situation is somewhat better on the Samsung SincMaster EX1920 monitor.

scrapcomputing, 2024-11-17:
I am trying to understand whether this is an issue with the TTL input section or the VGA output section.
1. Does this happen in other programs that fill the screen with color? Some LCD monitors have issues detecting the borders when the screen is mostly black.
2. Please try this new firmware.
[MCEBlaster_XBs4.uf2.zip](https://github.com/user-attachments/files/17791743/MCEBlaster_XBs4.uf2.zip)

Ruslan184, 2024-11-17:
Everything is ok in other programs.
Tried the new firmware - everything is great! Thank you very much!
I have 2 EGA cards and both works great.
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

scrapcomputing, 2024-11-17:
OK, so the issue is on the TTL side, the border detection is slightly off.
It does look better, but it seems that some pixels are still missing though. This firmware might be a little better:
[MCEBlaster_XBs8.uf2.zip](https://github.com/user-attachments/files/17792038/MCEBlaster_XBs8.uf2.zip)

Ruslan184, 2024-11-18:
The latest firmware cuts the image already on the right.
The ideal would be something in between XBs4 and XBs8.
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

scrapcomputing, 2024-11-20:
Thanks for trying it out, I will see what I can do.

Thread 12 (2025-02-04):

Olivetti M19 support

jdelange, 2025-02-04:
Hi, we had a short exchange on YouTube. I thought this might be a more appropriate channel for further discussions. If not, let me know!

As mentioned on YouTube I would like to use your blaster on my old Olivetti M19. To do so, I have to do some pre-work: converting the 16 color analog gray scale image to digital in such a format that your blaster can read it.

So I am currently looking at a suitable ACD (TLC5540 should work). This has a min clock frequency of 5 MHz. It's 8 bit, but I will only be using 4 bits. Screen res is 640 x 400. V-sync is about 45 Hz.

My question : what frequency should the clock of the ADC be set at? What determines this? The pixelclock of the M19? If 5 MHz is still too high, I know I can poll the ACD at a lower frequency, but I do not yet know how.

What else do I need to do with the 4 digital outputs (as I understand it I can throw away output 1 to 4 and keep 5 to 8) of the ADC to make it compatible?

Thanks for any help with this! Cheers, Jan

jdelange, 2025-02-05:
Following up on the above: I am a bit further in my knowledge (thanks ChatGPT!):

1) The ADC needs to be fed with the pixel clock frequency. There is no direct output from the PC, so this needs to be generated. (I think there is also a sophisticated/complex PPL way to regenerate the pixel clock?). There are inexpensive clock generators that can do this, so that should be doable. Question: could the Pico generate this clock also? (need to confirm, but I understand it is around 17 MHz).
2) The ADC needs to sync with the signal (or I need to use an FPGA after the ADC to filter out the relevant data). The ADC can be synced with the H-sync that is available from the PC. With this I can reset the ADC at every line.
3) To limit the output data of the ADC to the visual information only I can a) add a binary counter which is also fed by the same clock. This can count the relevant pixels and throw away the rest, or again I can use an FPGA fed with the H-sync. Then the ADC does not have to be reset, the FPGA will select the useful data.
4) Question: could the Pico perform the FPGA function also?

I am inclined to go for the binary counter as it is the simplest and cheapest solution.

Keen to get your advice!

scrapcomputing, 2025-02-06:
Oh I hadn't realized it was 16-level grayscale and analogue! I thought it was 4-level TTL but with different V H frequencies. The MCE Blaster can only handle MDA-style 4-level grayscale (1 video bit and 1intensity bit). Supporting 16 levels would require quite a bit of rework on the software side (I think we can reuse the 4-bit CGA input from the hardware side). But to get started we could just use 2 of the 4 bits, which shouldn't require too many changes on the software side.

Regarding how to get a digital signal from analogue, this looks quite challenging. You may be able to use a Pico to generate the pixel clock signal, but the main challenge will be getting it synchronized with the Horizontal sync while avoiding aliasing issues. There may be existing hardware (or FPGA?) projects on this, I have not looked into this myself. You could do this with a Pico but it's not that easy. The reason is that its clock dividers for the PIOs have an 8-bit resolution, which is not enough to avoid aliasing, so will most probably need adjust both the divider and the instruction delay. I think this would be the hardest part of the project.

But yeah, the idea of using an ADC with some kind of hardware (or perhaps a Pico) to convert the signal to 4-bit digital, then feed that into a second Pico running a modified MCE blaster firmware to get VGA, seems to be on the right track.

goatM19, 2025-02-07:
Hello, I can chime in with more information.

On the other side of this graphics card sits a regular monochrome TTL monitor, the card is using PWM to generate analogue signals that drive a MDA/Hercules screen to multiple intensities.

This is example from ATI and Tecmar :
https://www.vogons.org/viewtopic.php?p=440757#p440757

Possibly, this is the same system as in Paradise PVC4 described officially as "Support for color simulation on monochrome monitors using Paradise Color Simulation chip (PSC)".

Commodore PC-10 III is using the same Paradise hardware and same type of output. (M19 has a non-integrated predecessor of Paradise PVC4)

If it's out of domain of mceblaster to read in pwm inputs maybe a second microcontroller can be used to reverse the PSC chip signals back into 4 bits.

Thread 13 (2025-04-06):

Recommendation for MDA/Hercules modes

Maxx1234, 2025-04-06:
I understand that with old TTL CRT monitors, the user could adjust the vertical size in order to get an image with a "proper" aspect ratio with MDA/Hercules modes.

Unfortunately, (to my knowledge) this is not the case with  the majority of modern flat panel displays - these modes appear to be vertically "compressed" and there is no means to adjust the vertical size.

*If* a 1024x768 resolution could be used for MDA/Hercues modes, maybe horizontal "line doubling" could offer a more normal aspect ratio?
Any other ideas?

Thank you in advance, MCE Blaster is a really cool, simple and elegant solution!

scrapcomputing, 2025-04-07:
Yes, using 1024x768 VGA with line doubling should look a better in MDA/Hercules. The only problem is that I don't think that the Pico is fast enough for 1024x768 as it requires higher pixel rate than 800x600. Pico 2 is a bit faster so it may be able to handle it. I will experiment with it and I will keep you posted.

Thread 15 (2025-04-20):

need support... green v  and h sync at crt to vga

hitchhiker85, 2025-04-20:
hi

i have a old cnc system from east germany where the monitor is dead.

h sync about 15656hz 5v
v sync about 48-51hz 5v
green video 5v hz doesnt know.

is this possible with the mce blaster?

i have all but not the levelshifter.. but different shiftes on transistor basics.

is it worth to try a breadboard?
what do you think?

thanks

scrapcomputing, 2025-04-20:
Hi,

The MCEBlaster works with monochrome MDA compatible signals with a pixel clock around 16.257 MHz and resolution 720x350. By default it needs a VSync signal with negative polarity. If your device does not match these specs it may still work after modifying the timings in `firmware/src/TimingsVGA.h`. I could send you a custom firmware if you can figure out the specs of your device.

As for the level-shifter, most level-shifters should work as long as the pinout matches. In my prototype I was using a transistor-based level-shifter and worked fine with most cards. Ideally the level shifter should be TTL compatible, because 2V is TTL high, but this value is CMOS low.

I hope this helps

hitchhiker85, 2025-04-20:
ok i copy the MCEBlaster.uf2 to the pico2.. but it doesnt restart self... if i unmount safety.. and plug them again to usb nothing happend.. with the bootsel button pressed i see a empty pico2...

hitchhiker85, 2025-04-20:
ok pico2 blinks now.. my failure...

my video output is a 15pin svga female socket.
there are one dipswitch to invert vertical sync.
inside the controller there is a dipswitch for "highres".. highres doube/quad the picturesize.

i attached you all 3 signals with the vertical as normal and inverted and the video as normal and highres.
i know that the highres dip active make on a vga crt monitor a fullscreen. if it not active its .. i would say 1/4 picture in the left top corner. possible its a little bit more.... like 1/3.

i toke the screenshots of my scope everytime with the same picture information.. so all screenshots made with the same condition. only the 2 dipswitches changed.

Now some pictures AND THANKS FOR THE HELP!

Video GREEN PIN 2 HIGHRES DIP ACTIV
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

Video GREEN PIN 2 HIGHRES DIP !!!!!!NOT-ACTIV!!!!!!
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

HORIZONTAL SYNC PIN 14
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

VERTIAL SYNC PIN 13 INVERTED ACTIVE
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

VERTIAL SYNC PIN 13 INVERTED !!!!!!NOT-ACTIVE!!!!!!
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

hitchhiker85, 2025-04-20:
ok i wired up:
green from pico to vga cable to tft monitor
gnd from ico to vga cable to tft monitor
h sync from pico to vga cable to tft monitor
v sync from pico to vga cable to tft monitor

cable tested befor.. no picture.. it says no signal from cable n monitor.

i think PICO 2 doesnt work out of the box with your firmware

hitchhiker85, 2025-04-20:
i do some research.. i know that on a old vga crt where you can see datas i had something like this datas: i write it down on a scrappaper with s deqd pencil... reading like:

720x576 Resolution
33.1khz Horizontal Sync
55.9hz Vertical Sync
30.1mhz Pixel

but this was in hi res mode of the controller... i cant really remember which monitor it was.

scrapcomputing, 2025-04-20:
I have not tried the Pico 2 yet. Can you try with a Pico 1 first? You should be getting a VGA signal with the Scrap Computing logo when TTL is disconnected.

Do you think you can count how many hsync pulses fit between two consecutive vsync pulses ? This will give us an upper limit of the vertical resolution.

scrapcomputing, 2025-04-20:
> 30.1mhz Pixel

30MHz pixel clock is too high. The fastest I had tested is ~16MHz for MDA.

How about low-res mode?

hitchhiker85, 2025-04-20:
in low i cant see anything about this because i dont have the monitor anymore...
i have no pico one.. only pico 2... you have for the pico nothing ready right?
tomorrow morning i will make more screenshots from scope.
what would be perfect?
h and v sync together over 2 channels? its a super cheap aliexpress usb scope.. but i can try everything...thanks for help!!!

hitchhiker85, 2025-04-21:
i am now back.. if you need more information let me know.. i ordered a raspberry pi pico 1...
hope for a pico 2 solution :) but i think on wednesday ithe pico 1 is there.

the pico2 doesnt flash..

hitchhiker85, 2025-04-23:
if i change on cnc controller something picture do nothing....

scrapcomputing, 2025-04-24:
1. You measured around 330 horizontal pulses so the vertical resolution is less than 350, so it should fit fine within the supported MDA resolution 720x350. But both your HSync and VSync are positive, which is not standard MDA, so you need a special firmware (please try the one attached). The attached firmware is for MDA only and works at 15.7KHz HSync and around 60Hz VSync.
2. The MCE Blaster shows an on-screen message with the detected video mode, like "CGA 640x200". What does it show in your case? It seems to me that it's not being detected as MDA. If it were MDA the graphics would be white, not green. Which brings me to my last question:
3. Are you using the project's PCB or are you using a prototype board ? If you are using a prototype board please make sure you connect GP8 and GP9 as shown in the schematic, otherwise MDA won't work.

[MCEBlaster_MDA-only_VSyncPos_15.7KHz_60Hz.uf2.zip](https://github.com/user-attachments/files/19885814/MCEBlaster_MDA-only_VSyncPos_15.7KHz_60Hz.uf2.zip)

hitchhiker85, 2025-04-24:
ok i try it in some hours.
thanks for your answer.
i only connect green because i have only green.. but now i understand... green is the tube.. not the picture..

hitchhiker85, 2025-04-24:
what is connected to gp18 gp19? i only have one wire for color and this is green.. gp18 gp19 parallel??

hitchhiker85, 2025-04-25:
can you please explain what i need for pg8 and pg9? from the controller comes only green as video. no other!... 4 pins! gnd ,v,h,green video!
but i recheck with standart firmware.. think i have a broken rasp. main chip goes hot from the first day.

hitchhiker85, 2025-04-26:
good morning. yesterday i got the pcb. i test my rasp pi pico.. it doesnt read on all pins . i send it back and get today a new one. i double check my levelshifter and all is ok.. possible i get a dead clone.  dont know. .. now i ask again... pg 8 and pg 9 get what? i only have video h and v sync and ground.

thanks

scrapcomputing, 2025-04-26:
Hi,

I still don't know if you are using the project's PCB or not. It is very hard to debug the issue if I don't understand how you wired it up. The TTL inputs are wired into different GPIOs depending on the TTL mode, so if you haven't wired it correctly it won't work, or it will be detected as the wrong TTL mode (i.e., CGA instead of MDA).

If you are using the PCB you don't need to worry about the GPIOs, just connect the DB9 pin 7 to video and pin 9 to intensity if you have one (see https://en.wikipedia.org/wiki/IBM_Monochrome_Display_Adapter).

If you are not using the PCB you should follow the schematic and make all the necessary connections. If I understand correctly your input is MDA, so then the video signal should be connected to GP27 (after the level shifter). But please use the PCB if you have one, or at least wire things up as shown in the schematic, it will just make things a lot easier to debug,

hitchhiker85, 2025-04-26:
hi i have the project pcb with the tht style.
my levelshifter is the TXS0108E breakout board. i have transistor based level shifter as second option. the 74... ic i cant get quick..

i have no intensity! so from my cnc controller i dont get intensity..

i checked with my scope that the levelshifting works. all 3 signal (video h and v sync) are ttl 5v.. after levelshifter they are 3.3v without changing the frequenzy.

i now waiting for amazon and 3 new pico 1 with rp2040.
i think in 3 or 4 hours i get them..

main issue was the pico... wrote a code to test all in and outputs.. some are dead.. that was the thing i decide to order from other seller.

hitchhiker85, 2025-04-26:
do you mean pin7 video pin6 intensity right? 9 is sync... typo or is it more complex?

hitchhiker85, 2025-04-26:
amazone comes in the next hour... cross fingers

scrapcomputing, 2025-04-26:
Great!

OK so it seems that your vertical resolution is nowhere near 350 lines, it's more like 200.
For the horizontal part you just need to increase the pixel clock: keep pushing the "PIXEL CLOCK" button until the image fits on the screen.

Modifying the sources is **very** tricky because this mode is not supported, and it's not as simple as changing a few entries from a table. I am working on adding support for such non-standard modes through an on-screen menu.

hitchhiker85, 2025-04-26:
ook. do you want to make a file that i can test?
i think vertical must be 50hz not 60hz or??. i dont know.
pixelclock down takes ling time... possible to make it over file??..

thank you so much!

scrapcomputing, 2025-04-26:
I am working on it, I will let you know once it's ready :)

There is no faster way to reduce the pixel clock at the moment. But once you exit the pixel clock mode it gets saved in flash so you won't have to repeat the process.

hitchhiker85, 2025-04-27:
i came out to perfect picture with a pixelclock of 14.494MHz. some pixel drifting or gt shadow.. doesnt matter. nice!

but can you send me the modified source ??? please :)

hitchhiker85, 2025-04-27:
is it possible to get it in size of the screen? or is this another *project*?

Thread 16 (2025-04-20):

Can it handle inverted CGA

Fletch5, 2025-04-20:
I have an old Slot machine that uses an inverted CGA signal,
I best i can tell the H_sync and V_sync are both neg. and the colors are all inverted to negative as well.
The original CRT had the function built in to reinvert the color back to normal.

Is it possible in the firmware to invert the colors when they are read in?
And can the firmware handle inverted sync signals?

Thanks for any help, and this is a great project.

scrapcomputing, 2025-04-20:
It can work with some changes in the firmware. The VSync polarity is set in TimingsVGA.h but HSync is currently hard coded in the pio code.

Could you try the attached firmware in case it works?

[MCEBlaster_inv_polarity.uf2.zip](https://github.com/user-attachments/files/19827126/MCEBlaster_inv_polarity.uf2.zip)

scrapcomputing, 2025-06-29:
The latest firmware auto detects both H and V sync polarity, so the inverted signal should work.
Please let me know if you have any success with it.

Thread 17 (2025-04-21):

CGA Problems with Motorola R2600 RF Analyzer

TB1632, 2025-04-21:
Hi,
First thank you for this great work. Unfortunately i got some Problems with an RF Service Analyzer Model Motorola R2600B.
The Unit has an CGA Output, No more desribed about the Mode or the Video Chip. The Video Signal comes from an Asic, no more described  I got no full Picture, The Picture is Horizontal and Vertical cut off. I tried several Monitors, forced VGA Resolutions and all possible things.

The Positive: The MCE Blaster works great with another RF Service Analyzer Model IFR 1600S . It has an EGA Output. The MCE Blaster does a really great Job ! So the Unit assembled by me works.

Aditionally i own an GBS 8219 Converter which accepts the CGA input from the Motorola. I also own an old (Amiga) Monitor Philips CM8833 II (clone of 1084S) which accepts the CGA also.

I am no Video specialist and my knowledge is only minimum Basic.

So i took some Pictures. First 4 the Motorola problems

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

2 Pictures with the working GBS8219

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

And the working MCE Blaster with an EGA input from an IFR 1600

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

I am happy for any help and improvisation.

scrapcomputing, 2025-04-21:
It's missing like 20% of the vertical screen. So it could be a non-standard CGA mode with more vertical lines. The MCE Blaster prints the detected mode, is it CGA 320x200 ?

TB1632, 2025-04-21:
No, it detects 640 x200 CGA at 60 Hz , but, have a closer look there is missing about 20% of the Bottom and 20% of the right corner. Pressing Auto Adjust does no changes.

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

TB1632, 2025-04-22:
hi, its positive. pin 8 + 15,7 khz pin 9 60 hz positive

scrapcomputing, 2025-04-23:
Thanks! Could you try the attached firmware? I changed the CGA resolution to 640x350, similar to EGA. Let's see if it works :)

<!-- Failed to upload "MCEBlaster_CGA_640x350.uf2.zip" -->

TB1632, 2025-04-23:
I cant find any other firmware, sorry...

hitchhiker85, 2025-04-24:
same problem in my thread.. i think need a special formware :( thanks

scrapcomputing, 2025-04-24:
@TB1632 Oops sorry about that. The attachment had failed to upload for some reason. I fixed it in my original comment.

TB1632, 2025-04-24:
Hi, i tried the modified Firmware but nothing changes. Missing Bottom and right Corner. Blaster says CGA 640x200 at 60 Hz. 14,257 Mhz Pixl Clock. VGA Monitor says 720 x 400 V 70Hz H 31Khz. I have checked all Settings and Resolutions. No Changes.
Problem ist still the same.

If you are able and want spend some time for me, i will check other modified Firmwares which you provide.
Thank you..

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

scrapcomputing, 2025-04-25:
I think I forgot to disable line-doubling, this should make it fit vertically. As for the width I think increasing the pixel clock on the MCE blaster should make it fit horizontally. Please try the attached firmware in case it works this time.

Do you think you could measure the vertical resolution by measuring how many HSync pulses fit within two consecutive VSync pulses? This should help us with filling in the correct values.

[MCEBlaster_CGA_640x350_15.7KHz_16.267MHz.uf2.zip](https://github.com/user-attachments/files/19901340/MCEBlaster_CGA_640x350_15.7KHz_16.267MHz.uf2.zip)

TB1632, 2025-04-25:
Hi.
I have testetd the new firmware. Blaster initiates with your logo and colorbar screen. If i put it to the cga conector vga signal goes off and i got a black screen. i tried several monitors all the same , No VGA signal..

scrapcomputing, 2025-04-25:
Hmm please try this one.

[MCEBlaster_CGA_640x350_15.7KHz_16.267MHz.uf2.zip](https://github.com/user-attachments/files/19911515/MCEBlaster_CGA_640x350_15.7KHz_16.267MHz.uf2.zip)

crasbe, 2025-04-25:
@TB1632 took some measurements with his oscilloscope and frequency counter of the HSYNC and VSYNC signals.
I'm writing on his behalf because he is currently busy with less-fun work.

These are the oscilloscope measurements:

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

And this is from the frequency counter:

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

From the values it looks like the line count is 261 or 260 (depending on if you count the HSYNC pulse during the VSYNC):
15,723.269Hz / 60.2524Hz = 261.0000

<hr/>

Later this evening we want to try to measure the pixel width of of green frame or the blue grid, as they should be discernable on the oscilloscope.
With the pixel width, it should be possible to estimate the horizonal pixel count by dividing the time between two VSYNCs by the pixel width we measured.

crasbe, 2025-04-25:
We tried to measure some individual pixel widths.

I assume that these are 6 pixels, around 560ns:
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

And that this are 2 pixels, around 185ns:
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

With the 15.723269kHz VSYNC, we have 63.60000µs per line.

That would give the following pixel counts:
63600ns / (185ns / 2) = 687.57px
63600ns / (560ns / 6) = 681.43px

Unfortunately this is somewhat at the end of the bandwidth of this oscilloscope, it's only a 20MHz scope.

I am not super sure though that those are actually 2 and 6 pixels. It would be possible that it's actually just 1 and 3 pixels, which would result in a resolution of 340x260px and they were just pushing the limits of what an external CGA monitor could reliably show 🤔

<hr/>

This is the image with the latest firmware:

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

crasbe, 2025-04-25:
I just wanted to express how grateful we are that you are investing your time to find a solution here, this is really awesome :)

If the tube or transformer were to die in the RF analyzer, there would be no replacement available and external CGA monitors or converters are increasingly hard to come by.

scrapcomputing, 2025-04-26:
Thanks for the measurements and for trying out the latest firmware.

260 HSync pulses is similar to standard CGA. This is usually 200 visible + 60 black. But I think in this case it is probably closer to 240 visible + 20 black. The only issue is that this needs to use VGA's 640x480 resolution, not the 640x400 one I am currently using.

scrapcomputing, 2025-05-25:
Hi,

I have been working on a new firmware that should work better for your use case.
It is now stable enough for testing and it supports manually setting the TTL options:

- Press both buttons until the new menu shows up. The text [AUTO-TTL] should show up.
- Press the PxClk button once to change it to [MANUAL-TTL] and more options will show up including Mode, resolution and X and Y offsets.
- Cycle through the options by long-pressing either button, change values by short-pressing.
- The settings are saved to flash after 5 seconds or so.
- If you need to reset to defaults unplug the MCE Blaster from power and power it on again while pressing both buttons until you see the led blinking fast.

Please note that I have not done extended testing so feel free to report any bugs.

Thanks!

[MCEBlaster.rev.0.2.beta.uf2.zip](https://github.com/user-attachments/files/20432603/MCEBlaster.rev.0.2.beta.uf2.zip)

scrapcomputing, 2025-05-26:
Just FYI: I just uploaded a new version of the firmware: https://github.com/scrapcomputing/MCEBlaster/releases/

TB1632, 2025-05-27:
Hi.
I have testet the new Firmware. Now i am able in CGA Mode 640x240manual  to see the whole Picture, but only if i scroll manual the X and Y Axis.
It seems the CGA Resolution from Motorola is lager than 640x240, this is abolutly out of Norm. I could not choose higher Resolution in Blaster Menu in CGA and EGA Mode than 640x240. Also the VGA Mode does not switsch higher than 640x 480.

If it would be possible to go higer in resolution EGA CGA than 640, the VGA Mode will not be enough.

So i played arround with the MDA Mode(which is not usable in my case)  In MDA Mode its possible to go higher than 640x240 and the VGA Output switches to 800x600. So i was able to see the full Vertikal Screen , but changing Horizontal Resolution more than 240 the Blaster crashes and freezes. I have to do a Power Cycle and Change back to CGA or EGA.

Please dont waste Time for me for MDA Mode. Perhaps more Resolutionthan 640x240 in CGA Mode and automatic switching Output VGA to 800x600 can solve my Problem.
Thanks a lot for your Work

scrapcomputing, 2025-05-30:
Ah nice, it already looks much better!

> I decreased the 240 resolution down about 100 , the "Ratio" Changes to 1/2 but the Picture is not shown full, 20 Lines are missing... so I turned back to 240.

I think you should increase the vertical pixels from 240 to 260, not decrease them. Because it seems that your input is 260 lines. At 240 you 20 lines won't show either from the top or from the bottom or both, depending on the Y offset.
So please try 260 vertical by setting Manual TTL to: "MANUAL-TTL EGA 640 x 260 X: MANUAL 8 Y: MANUAL: 0".

TB1632, 2025-05-30:
Yes this is a logic result to increase up to 260 but its not adjustable, Blaster settings stops  at 240.  I dont know if 20 lines are enough, perhaps it will be 22 or 23..  but as is said it ends at 240 max.

scrapcomputing, 2025-05-30:
This must be a firmware bug, I will look into it and I will get back to you.

TB1632, 2025-05-31:
Easy... easy, let me know how I can support you !!

scrapcomputing, 2025-05-31:
For vertical resolutions 240-260 we would ideally switch to VGA 800x600 with line doubling but the Pico is not fast enough to support 800x600 for EGA/CGA. Disabling line-doubling at 241 would just sqeeze things vertically which won't look great. So let's try writing more than 480 visible lines vertically, perhaps the VGA monitors can tolerate it.

Please try the attached firmware, it might work.

As for the colors I am not sure why they would change, strange.

[MCEBlaster.VGA520.uf2.zip](https://github.com/user-attachments/files/20535368/MCEBlaster.VGA520.uf2.zip)

TB1632, 2025-05-31:
OK we have reached the Goal !!
The CGA  Pic fits exactly in the VGA Monitor tolerance, i think it will not accetpt one Line more .
Please see the On Screen Text from Blaster in the VGA Monitor.

I have testet another Monitor ( Acer AL1716) fits exact the same, but have to play a little bit Pixl Clk with Blaster and Monitor. (normaly) The first Montor was an very old Gericom 15 inch. Native VGA max is 800x600, but is small and lightweight. Pefect for me in my Lab.

Increase Pxl Clk over 12 Mhz, correct Color comes back, i think this is a special issue by my Monitor.

I NEED your PP to support.

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

scrapcomputing, 2025-05-31:
Awesome! Thanks for trying it out. I will push this as the latest firmware.

> I NEED your PP to support.

You've already helped so much by testing and reporting issues, thanks so much!

TB1632, 2025-05-31:
YOU ARE WELCOME !!

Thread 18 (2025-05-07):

Possibility for 15.5kHz Hsync and 50 Hz Vsync (PAL TV)

roberto314, 2025-05-07:
Hi, i have an EVA-1 which is an Video Adapter for the HX-20 Computer. It outputs 15.5kHz/50Hz with one color. I tried every firmware available (even the ones within other issues) but none of them work well enough. Additionally the horizontal resolution is 480px and vertical 200px. Furthermore the unit can change between 80 characters / Line and 40 char/line.
I had success with one custom firmware (i can't remember which) but the picture was too big.
I used a 1920x1080 Screen and the picture was bigger than full screen. VSync is positive, HSync i am not sure.
Is there any way to add this mode?
What Informations can i provide?
Thanks,
robert.

scrapcomputing, 2025-05-07:
Hi Robert,
The current firmware was designed to be used with standard PC modes: MDA, CGA and both low and high-res EGA modes. It will auto-detect the correct mode by checking the VSync frequency and the VSync polarity.

Supporting other non-standard PC modes is possible but won't work well with the current firmware(s).
I am currently working on a redesigned firmware that allows you to configure your custom mode on an on-screen menu.
The firmware should be ready soon, I will share it with you once it's ready.

Thanks

scrapcomputing, 2025-05-25:
Hi Robert,

The new version of the firmware is stable enough and supports manually setting the TTL options:

- Press both buttons until the new menu shows up. The text [AUTO-TTL] should show up.
- Press the PxClk button once to change it to [MANUAL-TTL] and more options will show up including Mode, resolution and X and Y offsets.
- Cycle through the options by long-pressing either button, change values by short-pressing.
- The settings are saved to flash after 5 seconds or so.
- If you need to reset to defaults unplug the MCE Blaster from power and power it on again while pressing both buttons until you see the led blinking fast.

Please try it out it may work better with your EVA-1.
Please note that I have not done extended testing on it so feel free to report any issues.

Thanks!

[MCEBlaster.rev.0.2.beta.uf2.zip](https://github.com/user-attachments/files/20432595/MCEBlaster.rev.0.2.beta.uf2.zip)

scrapcomputing, 2025-05-26:
Thank you so much for the detailed feedback!

1. Oh I hadn't realized that. My monitor shows some artifacts but that's it. Anyway I made some changes which should improve things a bit. I also increased the time-out to 12s. I might add a save button in the future, but I usually try to avoid those because the user may spend time messing with the settings and then forget to save, which can be frustrating.
2. So what is happening is that the on-screen menu is using some CPU resources that make the TTL reader a bit slower, which ends up messing up the input image. My monitor doesn't get bothered by it at all, but I guess I need to try it on a few others. I have made some changes to that code which should improve this quite a bit.
3. Regarding the resolution you are right, the 640 I am showing is the sampling rate. This is an internal implementation detail which I should probably hide from the user eventually. The problem is that the output buffer is 640 wide but the input 320 which would require pixel doubling horizontally which is not easy to do. So what we end up doing is just sampling 640 at double the rate.
So to get the image to fit on your screen you need to decrease the pixel clock. This is not done in the "Manual TTL" menu, but under normal operation. Just click on the PxClk button once and then keep adjusting it with either button until the image fits.
5. X and Y are the horizontal and vertical offsets. They adjust the black borders from the last horizontal and vertical retrace. They should rarely need adjustment because because the auto-detection of the border usually works OK.

Please try the latest firmware: https://github.com/scrapcomputing/MCEBlaster/releases/

scrapcomputing, 2025-05-29:
Thanks for trying it out!

The pixel clock gets adjusted during "normal" operation (i.e., not in the Manual TTL menu).
With the input video signal connected and working, press the "PxClk" button once and the current pixel clock should show up on screen. It should display text like "PxCLK: 14.328MHz   CGA 640x200".
Now you are in the mode where you can adjust the pixel clock. Pressing the PxClk button increases the pixel clock, pressing the AutoAdjust button decreases it. You should still see the text on screen showing the current pixel clock value. When you are done changing its value just wait for 12 seconds without pressing any buttons and the final value will be saved to flash. You will see a message about it on screen and the pixel clock text will no longer be shown on screen.

The "TTL INFO" screen shows up if you press the PxClk button for more than 1 second. This should only work when there is input TTL signal. This should always work, not sure why you get a black screen.

I hope this helps, let me know if you are still having issues with it.

roberto314, 2025-06-01:
I think we have a winner! The Resolution settings are a bit weird (see pictures) but i've got it working.
It would be very helpful if you could add the Pixelclock to the new "Resolution Menu". At least the starting Point, i have 9.216MHz and starting from 14.xxx is really slow.

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

roberto314, 2025-06-01:
I spoke too soon. It looks like the firmware switches off Vertical doubling >260 Lines. This would be more original to the original Format (see the first pictures from the EGA Monitor) but i cant get the picture to center properly. I think the syncpulse polarity is wrong.

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

scrapcomputing, 2025-06-01:
Hi Robert,

Great to see you got a better image this time, and thanks for all your comments and suggestions!

>  It looks like the firmware switches off Vertical doubling >260 Lines. This would be more original to the original Format (see the first pictures from the EGA Monitor) but i cant get the picture to center properly.

Let me see if I understand correctly. You are saying that you would prefer to disable line-doubling for vertical lines < 260 ? I think I could add a menu option for it.

As for centering the picture there are two ways:
- By adjusting your VGA monitor. A lot of LCD monitors are pretty bad at centering non-standard images so you could try messing with the LCD monitor's manual image adjustments.
- By setting the X and Y offsets in the MANUAL TTL menu but these adjustments are rather limited.

In theory we should be able to adjust the borders in one more way: by adjusting the borders of the generated VGA signal but the Pico is not fast enough to handle the additional code needed for it. That might become available on the Pico 2.

>  I think the syncpulse polarity is wrong.

Are you referring to the HORIZONTAL SYNC in TTL INFO ? These are the values detected in the TTL input. This is probably related to your suggestions (see below), but I don't really understand what you mean.

> Unfortunately it doesn't sync on start. It uses 12.9kHz Horizontal Sync - which is totally off, 15.4 would be fine.

So you get no signal when the computer starts. Does the computer generate a different TTL signal on start which doesn't match the one you set on MANUAL TTL ? If so could you check if one of the sync polarities changes between the two modes ? If they do we could use it to have two separate MANUAL TTL "profiles", one for each input mode.

> 2nd Suggestion: Change Sync Polarity via Menu or accept negative values for x- and y- offset.

I don't really follow how the sync polarities and the X/Y offsets are related. Then TTL input sync polarities are auto-detected and you don't need to mess with them. The output VGA sync polarities are fixed and don't need to be adjusted.

> 3rd suggestion: Horizontal sync window, or fixed value.

This is probably related to your 2nd suggestion, I don't really follow. Could you please elaborate a bit ?

roberto314, 2025-06-01:
1st point: I find the 260 Lines limit no problem at all. I think it looks more authentic now, without the doubling. If one would like the doubling, just decrease the lines to <260.
2nd point: I made the observation that if the hsync polarity is wrong the picture is shifted somewhat because the Receiver (whatever TV that may be) uses the rising or falling edge only. So for ex. the polarity is pos. and the receiver uses falling edge, that means second egde, if the polarity is reversed the falling edge is the first one and so the picture is shifted.
I can't adjust my monitor more.
3rd point: I found out that if i increased the Pixelclock to 9.217MHz the autodetect of the sync pulse works.
4th point: Output sync pulses are out of the question, just input sync.
Addendum: I just found out that i had Composite Sync on Hsync. I removed the jumper and now the sync gets correctly detected as +/+.
Just the positioning of the windows would be a small ehancement. Is there a possibility to enter negative offsets?
Right now everything works fine. Even after power on.

scrapcomputing, 2025-06-22:
The latest release (V 0.3 beta 1) adds the negative offset feature, feel free to try it out.

Thanks!

roberto314, 2025-06-29:
I am in the middle of another Project. I will give feedback when i get the chance.
--robert

scrapcomputing, 2025-07-09:
Thanks for the feedback.

Unfortunately these options cant' work with large values because then we run into timing issues, i.e., the pico doesn't have enough time to do the necessary processing between the end of the previous line/frame and the new one.

Not sure why the vertical one doesn't work at all, I will look into it.

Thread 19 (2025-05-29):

Does not work  MCEBlaster V 0.2 beta 1

Rapovoz, 2025-05-29:
Hi!
With firmware version V 0.2 beta 1, the pi pico reboots but the blue LED does not light up. There is no No Signal label when connected to the monitor.
With the firmware MCEBlaster_rev 0.1c.uf2, everything works as expected.
I tried the firmware https://github.com/scrapcomputing/MCEBlaster/issues/17#issuecomment-2908066771 it starts but freezes after 5 seconds

scrapcomputing, 2025-05-30:
Hi,
Ah you must be using one of the clones that have slow flash memory.
I had to bump up the frequency for this version of the firmware because it was slowing down the program and was causing artifacts on screen, sorry about that.
I will try to reduce the flash memory frequency again at some point, so please keep an eye on the new releases.
Thanks!

Rapovoz, 2025-06-24:
> Hi, Ah you must be using one of the clones that have slow flash memory. I had to bump up the frequency for this version of the firmware because it was slowing down the program and was causing artifacts on screen, sorry about that. I will try to reduce the flash memory frequency again at some point, so please keep an eye on the new releases. Thanks!

Hi!
I have a pi pico board like this

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

Is it possible to solder the flash memory or replace the entire pi pico?

Version 03 also freezes like 02, but it gives a better picture at the start. But for some reason it defines the signal as ega and not even though we have a cga (320x200) like that.

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

scrapcomputing, 2025-06-25:
I would just use an original Pico instead. Not sure if/how you could replace the flash chip.

I did try  reducing the flash frequency back to 1/4 of the CPU frequency, but I couldn't remove the artifacts, so  I am not sure this will get fixed soon.

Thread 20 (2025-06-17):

There is flickering in MDA mode.

yyartsworld, 2025-06-17:
I made a MCEBlaster.
It works as explanded.
But There is flickering.
I also can see flickering in your youtube video. It is same as mine.
Is it possible to get better in the future version?

Thankyou for your effort.

yyartsworld, 2025-06-23:
Hi!
I tested the new feature.
with pixel clock 16.257MHz and sampling offsets 4
It became perfect. the noise was gone.
but after computer reboot, sampling offsets go back to 0
I think sampling offset state was not flashed.

Thankyou very much!! I love this project.

yyartsworld, 2025-06-23:
I tested more on V 0.3 beta 2.
I found this.

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

I can't explain in english. so i uploaded two images.
I am using a CRT monitor.
I tried to fix this using MCEBlaster and my Monitor. but I couldn't find out any solution.

Thankyou!!

scrapcomputing, 2025-06-23:
So what is happening here is that these games are drawing the graphics several pixels to the right compared to the DOS prompt. In my case this gets fixed by pressing the auto-adjust button.

I think I may be able to fix this for MDA. I think I just need to use a wider line, which I can do because in MDA I am using 2 pixels per byte, so we do have enough memory for this.

Thanks for the bug report and I will keep you posted.

yyartsworld, 2025-06-23:
Hi!
I am not 100% sure i understand what your next plan is.
but I have some suggestions.
I prefer one pixel line. because i have a CRT color monitor.
I want similler expeaience like when i play herculess game with original mono CRT monitor
and I like natural scanline not by filtering
I know there are not many crt user but using of upscailing make us give up several merits CRT monitor can do

Thankyou.

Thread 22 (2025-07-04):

Tandy 2000

jnewkirk5, 2025-07-04:
Would it be possible to add support for the Tandy 2000?

scrapcomputing, 2025-07-04:
I couldn't find much information about Tandy 2000 graphics.
If it's like standard Tandy graphics it should be EGA pin-compatible so the MCE Blaster should work for smaller resolutions up to 640x350. 640x400 isn't currently supported because of Pico's limited memory, but it should be possible to support it using a Pico 2 (once the port is ready).

Could you point me to some specs for Tandy 2000 graphics, so I can take a look?

Thanks!

jnewkirk5, 2025-07-04:
http://cini.classiccmp.org/pdf/Tandy/Tandy%202000%20Technical%20Reference.pdf

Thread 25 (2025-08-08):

Text Application in MDA

yyartsworld, 2025-08-08:
Hello
I found a new bug.
When i use text mode application like Edit right side is not shown completely.

MCEBlaster
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

86box
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

Bs0Dd, 2025-09-08:
Same problem

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

The image is cut at the right when the correct pixel clock is set (my card has a 16MHz oscillator).

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

I can see the entire screen if I decrease the clock, but then, of course, I have a noisy image

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

Same situation with the Hercules Graphic mode

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

Tested on the Paradise Hi-Res Graphics Card (MDA/Hercules mode) and IBM EGA (MDA monitor mode).

scrapcomputing, 2025-09-10:
Yeah, it looks like the width is missing 4 pixels or so. I will need to look into it.

As for the screen width being reported as 752, this is deliberately wider to mitigate for the inaccurate offset detection. So instead of showing 720 pixels horizontally we are showing 720 + 32 (=752) which includes some black borders. But this is obviously not working as expected given the missing width.

scrapcomputing, 2025-09-14:
@yyartsworld Could you try the latest release? I increased the buffer size in MDA. I don't see any clipping on the right hand side.

@Bs0Dd I increased the buffer size for the Pico 2 firmware and it seems to fix the Checkit tests. Sadly I can't do the same fix for Pico 1 because it's running out of memory.

yyartsworld, 2025-09-14:
I tried v0.3 beta 8 Pico 1.
the Clipping disappeared.
Thankyou very much!

scrapcomputing, 2025-09-14:
I think the centering issue may be related to the VGA timings for 800x600@56Hz. I am currently using:
- H Back Porch: 128
- H Visible: 800
- H Front Porch: 24
- H Sync: 72

- V Back Porch: 22
- V Visible: 600
- V Front Porch: 1
- V Sync: 2

But I don't know if these are correct.

I changed the values a bit and the image did move a bit to the left or to the right, but I could not get it perfectly centered. Perhaps these values are off and the monitor tries to guess the image placement, or perhaps it expects some ON pixels 800 wide and it does not see any so it gets confused and cannot center the image properly. And by the way my monitor reports 800x600@60Hz, which is not correct.

scrapcomputing, 2025-09-14:
@Bs0Dd please try out the latest release (v0.3 beta 9), it should fix the horizontal clipping in EGA 640x350. I managed to increase the horizontal buffer size in the expense of the extra vertical buffer size, which is now 0. I also increased the number of offset values to 16. Let me know if you encounter any crashes/hangs (usually caused by out-of-memory errors) or perhaps any vertical image clipping.

Bs0Dd, 2025-09-15:
Oops, looks like the situation is worse now.
The right side is still cut (so the fix doesn't work), but now the bottom part of the image is also cut, and there is a blinking line.

beta8/beta9

https://youtu.be/YGJCQlt3OtU

As I said earlier, I can see the full image if I change the pixel clock (in both directions), so maybe it's something related to this?

https://youtu.be/1nwrhIEix2Y

Bs0Dd, 2025-09-16:
> Have you tried different sampling offsets other than 0? Because in my case I could see the whole image with a sampling offset of 15 or so.

Yes, I tried; bigger offsets allow seeing a bit more, but it is still cut (as you can see by the "p" letter in the clock).

https://youtu.be/onecqhKIcE0

Adjusted offset / Wrong clock set

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

scrapcomputing, 2025-09-17:
I think I fixed it, please try the latest release (v 0.3 beta 10).

Bs0Dd, 2025-09-17:
Not so optimistic again.

Firstly, now in the first offsets, the lines twitch but stop while the menu is open (then it starts again).

https://github.com/user-attachments/assets/2a25bc53-f8c6-4b7d-9a8d-31ce363ca08a

I compared the results of the offset adjusting and got the following:

Offsets ~0-9:
Three pixels cut, as always (reference screenshot from the 86Box)

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
<br><br>
Offsets ~1x:<br>
Two pixels cut<br>

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
<br><br>
Offsets ~2x:<br>
Only one pixel line cut<br>

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
<br><br>

Wrong clock ~16.278 MHz:
All pixels visible

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
<br><br>
Looks like we're on the wrong road, if it requires about 30 offsets to get a normal image on the original IBM EGA. Something there is definitely wrong...

And the image is still cut at the bottom (with a strange flashing line) since beta 9.

scrapcomputing, 2025-09-19:
@Bs0Dd beta 11 contains the sampling fix, please give it a try :)

I still need to figure out why MDA needs such a large buffer, it shouldn't need a 776 pixels wide buffer to display the whole image. This should also fix the image centering issue.

Bs0Dd, 2025-09-19:
Yep, it finally shows screen fully. But...

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

There are still "lines twitch" bug appeared in beta 10. I tried to revert this line and bug disappears but then I can't see menu in the CGA or MDA mode (monitor fails to display).

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

The CGA and MDA modes seems to be OK for the IBM EGA:

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

But looks like I have problems with Paradise card now. Old pixel clock values don't work for CGA and Hercules modes:
(CGA Beta10/Beta11)

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

And I tried to adjust it but... after 5 minutes can't get a noiseless image. Only something like this.

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

Similar situation with MDA/Hercules.

scrapcomputing, 2025-09-20:
1. Regarding the line bug, it seems that the line offset is a few pixels earlier every few lines. XBorder shouldn't have any effect on this because it is applied on the whole frame. And btw this needs to be 4-byte aligned otherwise the Pico will crash. I am not seeing this exact issue, but I do see some occasional noise which might have the same cause.
This could be some kind of timing bug related to the input from the PIOs, or related to some random delays in the TTL loop. So I decreased the extra loop iterations down to 2 which still shows no horizontal clipping (it should be safe to increase it back to 4 if needed) and also removed some functions from flash to reduce the random delays.
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
yyartsworld, 2025-09-21:
It appears when first run zeliard after booting.
i didn't do any auto adjust.

scrapcomputing, 2025-09-28:
@Bs0Dd Please check out the latest release (0.3 beta 13). It implements profiles. Long-press the auto-adjust button to cycle through them. As always feel free to report any issues you run into. Thanks!

yyartsworld, 2025-09-29:
Hi!

V 0.3 beta 13

I need to auto adjust every boot.
I think auto adjust setting is not saved.

scrapcomputing, 2025-09-29:
Thanks @yyartsworld for trying it out. I think I may have a fix for it, there was an unrelated change regarding the CGA and EGA border adjustment, so I reverted that. I deleted the old release and created a new one (same v 0.3 beta 13) which should fix the issue.

yyartsworld, 2025-09-29:
The auto adjust problem has been solved.
Thankyou very much!

Bs0Dd, 2025-09-30:
I already tried to reset it after firmware update. No effect...

https://youtu.be/FRbsEez-MQg

Maybe there are something my HP monitor dislike. I have no access to the oscilloscope now to check what's going on.

scrapcomputing, 2025-09-30:
Strange, I didn't change anything in the VGA section. The most probable cause is an out-of-memory error. I have been trying to fix those since the profiles increased the memory usage by a little bit. Such errors usually show up in the debugging console (using a terminal emulator like minicom, putty or hyperterminal).

I made some changes, so it might be fixed with the attached firmware. In case it doesn't get fixed please try a terminal emulator to check the Pico's debugging output, it should help us locate the issue. The device shows up as a USB serial device, /dev/ttyACM0 on linux and one of the COM ports on windows if I am not mistaken. The baud rate should be 115200.

[MCEBlaster_pico1.with_fix.uf2.zip](https://github.com/user-attachments/files/22610137/MCEBlaster_pico1.with_fix.uf2.zip)

Bs0Dd, 2025-10-01:
And now it works (other modes seems to be ok too)! So... the problem was in the memory insufficiency, right?

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

But why only I had this issue...

Bs0Dd, 2025-10-03:
Oops x2. Now the EGA mode is broken. And the MDA menu again.

I used an oscilloscope, and I see a problem with the Vertical signal in "broken" modes.

CGA mode (ok):
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

EGA mode (broken):
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

MDA mode (normal, ok):
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

MDA mode (menu, broken):
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

Very strange... maybe your monitor tolerates this, but not my HP of course, hah...

Bs0Dd, 2025-10-03:
P.S.2: lol, received this in my mail

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

scrapcomputing, 2025-10-04:
Thanks @yyartsworld  and @Bs0Dd  for trying it out. Ah now I get what you were saying about the video not working in the menu, I thought that the MCEBlaster would hang completely when you pressed the button. That's a relief! So it's not an out-of-memory issue. And yes, I can confirm on my side I am seeing these artifacts. I thought that theses were coming from the TTL Reader side, but obviously not! So the issue must be that some of the VGA writer functions are being placed in flash instead of ram.
I updated the beta13 release with a small fix that moves all vga writer functions to ram. This should fix the issue. Please give it a try.

Lol about the email. The sender is particularly interested in the MCEBlaster, maybe he is doing research in 40 year old pc video standards haha :D

yyartsworld, 2025-10-04:
In MDA mode, the noise issue was fixed.
Thankyou!

scrapcomputing, 2025-10-06:
Thanks @Bs0Dd for the thorough testing and for the button related bug (fixed).

I was getting artifacts in CGA without even entering the PxClk menu! Not sure how this can happen as EGA and CGA are using the same code... Anyway things improved a bit when I moved some more code to ram, and with some more tweaking. Sadly I can't place any other performance critical code to ram as there is not enough ram! I even had to shrink the No signal logo for the Pico 1 build :(

Please give beta 14 a try when you get the time, thanks!

yyartsworld, 2025-10-06:
There are several Unknown Mode Games. They have different resolution and vsync. so they have centering problem.

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

So I added 3 line in "TimingsTTL.def"

DEF_TTL(MDA_640x200_62Hz,  0, 752+XB,  0, 126,   20, 294+YB,  4-YB, 16,  Pos,  Neg, 18430, 62, 16257000, TTL::MDA)
DEF_TTL(MDA_640x300_45Hz,  0, 752+XB,  0, 126,   20, 374+YB,  4-YB, 16,  Pos,  Neg, 18430, 45, 16257000, TTL::MDA)
DEF_TTL(MDA_640x300_58Hz,  0, 752+XB,  0, 126,   20, 310+YB,  4-YB, 16,  Pos,  Neg, 18430, 58, 16257000, TTL::MDA)

I don't know if this is right way.
But I can get better result without unknown mode message.

yyartsworld, 2025-10-07:
Thankyou for good explanation.
I understand why there is no good solution for every game.
Actually, I am satisfied enough with current version of MCEBlaster.
And I wish MCEBlaster to be improved in the future.
Thankyou very much.

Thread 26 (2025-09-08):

Problems with VGA monitor

Bs0Dd, 2025-09-08:
There is a strange problem when using MCE Blaster with my HP LP2465 monitor from 2006.
If I use CGA or EGA modes, when the border is not black, there are problems with the brightness of the main part of the screen.

Black/Blue border

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

But if I push the adjust button when the border is active (so the image will be misaligned), there is no such problem.

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

It's clearly visible that the text's color changes when the border color changes

https://github.com/user-attachments/assets/39463fde-307a-4bbe-8447-be027dfa170e

However, my Samsung S22F350FHI from 2017 does not suffer from this problem.

https://github.com/user-attachments/assets/1aacf09c-01e3-47c8-8e92-f3fdb215095c

It appears that the border falls on the blanking intervals, so when it's not black, it produces a signal where it shouldn't be.
Modern monitor tolerates it, but older not.

scrapcomputing, 2025-09-08:
Thanks for the bug report, this is very strange!

Could it be related to the resistor values of the VGA DAC on the MCEBlaster ? Some users have reported that the signal is too "hot" for some old monitors meaning that the voltage is too high with the 422 / 845 ohm resistors. Could you try using 470 / 1K instead to see if that fixes the issue?

Bs0Dd, 2025-09-10:
Well... Looks like I found the source of the problem.
There are two borders (main screen is clean) of the normal old VGA card (OTI067 + OTI066ADV RAMDAC).
(Blue channel + H-sync.)

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<br>

And this is TVGA8900C + ADV476KN66 RAMDAC:

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<br>

So the positions are the same (Trident has more voltage). I measured it without connection to the monitor (can't do it easily), so the voltage is higher than it must be with the 75 Ohm resistance from the monitor.

Also, my SVGA 286 laptop (CL-GD6x0 + BT471KPJ50 RAMDAC):

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<br>

Looks like ~ standard thing (all three signals):

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<br>

Now, if I use the "MODE 40" command, in this video mode border will be bigger:

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<br>

There are strange things with my laptop - RAMDAC changes HSYNC's length, and the left (start of the new line) border is too close to the line's start. And...

There is a color problem like MCE Blaster has!

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

So I measured Blaster's signal too. And...

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<br>

Its left border also shifted as Cirrus (and HSYNC signal is a bit shorter than OTI/Trident has).

So I played with some settings.

There are good colors:

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<br>

One step back, and there are yellowish white and dark blue:

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<br>

So looks like my HP monitor requires at least ~740 ns of the back porch before starting to receive any color. And it measures the signal's level and sets it as "reference zero" for each line. That's why it suppresses color.

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<br>

OTI/Trident has ~1240 ns with "wide" border in the MODE 40.

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<br>

While Blaster always has only ~622 ns.

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<br>

So I think it needs to be shifted to the right, so the back porch will be bigger than the front porch, as it should be, as I understand (OTI/Trident also seems to have no front porch in MODE 40 at all, but it still works, so the back porch is the most critical here).

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

Bs0Dd, 2025-09-14:
Well, looks like the problem was fixed!

Closed 2025-09-14.

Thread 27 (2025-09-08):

Modifying code to add 640x400 monochome resolution with different scan freqencies

jdelange, 2025-09-08:
Hi, if I want to update the code to allow for a new resolution of 640x400 with 45.5 Hz and 81.6 kHz frequencies (ATT400 / Olivetti monochrome), then what is the easiest way to do this? 1) Add a new profile mimicking the other profiles and adjust as required, or 2) take an existing mode such as MDA (as this is mono) and modify this to the new parameters?

I am assuming that 2) doesn't require to change the menu / program logic etc. I have only scanned the code but I noticed some decisions / selections are made based on (hi)resolution. If I insert a new (hi) resolution this might break this logic.

This all based on the assumption that adding a new profile / resolution would work in this way.

Thanks! Jan

scrapcomputing, 2025-09-09:
The challenge is the amount of RAM available. The frame buffer is currently set to 720x350. Increasing it to 720x400 (or even 640x400) won't work because the Pico 1 does not have enough RAM. So the only option is to use a Pico 2 which contains double the RAM.

jdelange, 2025-09-10:
I am trying to build your code. I run into an error that I haven't been able to fix yet. Does this look familiar?

```
[build] C:/Users/jande/.pico-sdk/sdk/2.2.0/src/rp2_common/hardware_base/include/hardware/address_mapped.h:64:18: error: unknown type name 'uint64_t'
[build]    64 | typedef volatile uint64_t io_rw_64;
[build]       |                  ^~~~~~~~
[build] C:/Users/jande/.pico-sdk/sdk/2.2.0/src/rp2_common/hardware_base/include/hardware/address_mapped.h:13:1: note: 'uint64_t' is defined in header '<stdint.h>'; this is probably fixable by adding '#include <stdint.h>'
[build]    12 | #include "hardware/regs/addressmap.h"
[build]   +++ |+#include <stdint.h>
```
I tried the suggested fix to `#include <stdint.h>` at the top of the file, but then I get all kinds of other errors within that file.

jdelange, 2025-09-13:
Thanks, appreciate that. Other projects compile fine. What does your environment look like?

jdelange, 2025-09-14:
Tanks! I have a laptop with Linux Mint. I will try my luck on that.

jdelange, 2025-09-20:
Trying to build on Linux. I get the error below. It's missing `EGA640x350_PosHSync_delay04_offset17.pio.h`, but I would not be surprised that that file should not be called? That 16 is the max? Could this be an error in the CMake script? But then the question is: why am I getting this and you apparently do not?

```
MCEBlaster_pico1_EGA640x350_PosHSync_delay04_offset16_pio_h
[build] gmake[2]: *** No rule to make target '/home/jan/code/cpp/MCEBlaster/firmware/src/Pio/EGA640x350_PosHSync_delay04_offset17.pio', needed by 'EGA640x350_PosHSync_delay04_offset17.pio.h'.  Stop.
[build] gmake[1]: *** [CMakeFiles/Makefile2:4260: CMakeFiles/MCEBlaster_pico1_EGA640x350_PosHSync_delay04_offset17_pio_h.dir/all] Error 2
[build] gmake: *** [Makefile:91: all] Error 2
```

scrapcomputing, 2025-09-20:
Oops I forgot to push all files to the repository, which is why you are getting the build error, sorry about that. I just fixed the repository (and the latest release), they should build fine now.

jdelange, 2025-09-20:
Ah! Thanks. I removed my comment because I thought I was doing something wrong. Too many errors... Thanks for the update, that saves a lot of searching....

scrapcomputing, 2025-09-20:
Let me know if you run into any other build issues. It should build fine with: `cmake -DPICO_BOARD=pico -DCMAKE_BUILD_TYPE=Release -DPICO_FREQ=270000 -DPICO_SDK_PATH=<path to pico-sdk> ../src/ && make -j`

jdelange, 2025-09-24:
Ok. I have been able to compile the code. I think a lot of issues were due to the fact that I tried to create the project using the Pico code extension environment within VSCode which creates quite a different set-up . I have asked ChatGPT (which I have been using to guide me through the process) to summarize the possible reasons why our first attempts (also on Windows) may have failed:

```
Generator difference:

1. The Pico VS Code extension defaults to Ninja as the generator.

Your manual approach used Unix Makefiles (-G "Unix Makefiles").

CMake generators affect how build files are created and how compilation commands are run. If the project assumes Makefiles (paths, flags, scripts), Ninja can fail or behave differently.

2. Presets and SDK path:

The Pico environment may use its own CMake presets or environment variables that point to a different SDK location or board configuration.

If the project was written expecting a local SDK path (as you set manually), the default Pico extension paths could conflict.

3. Toolchain and flags:

The Pico extension might automatically select a different arm-none-eabi-gcc version or set extra compile flags, e.g., for USB, debugging, or frequency.

Your manual build explicitly specified the SDK path, C/C++ compilers, PICO_FREQ, and Release mode, which the Pico environment may not have matched.

4. Source folder and structure:

Your project has a nested firmware/src structure. The Pico extension might assume the top-level folder contains the CMakeLists.txt, so it could have been pointing to the wrong source folder.

So in short: the generator (Ninja vs Makefiles) is one of the main differences, but also preset paths, compilers, and folder structure likely contributed. The combination made the Pico environment build fail, whereas manually controlling all of these allowed you to succeed.
```

jdelange, 2025-09-24:
I am working through the code. I have decided to add a new profile.

jdelange, 2025-09-25:
I am looking at the CGA and MDA readLine() functions. For geometry I can follow the CGA set-up, for colouring I need to follow the MDA buff. I am trying to see if MDA allows for the intensity bit? This is what ChatGPT makes of it:
```

In Blaster’s code:

The MDA PIO config only grabs one pin (MDA_GPIO), and the comment in your snippet says:

_// in pins: VI (Video, Intensity)_

…but the implementation then only sets 2 pins in pio_sm_set_consecutive_pindirs(Pio, SM, MDA_GPIO, 2, /*is_out=*/false);.
That suggests it does provision for two pins: V + I.

In the buffer handler (setMDA32), it looks like it compresses 2 monochrome pixels per byte. Typically this assumes Video only. I haven’t seen intensity actually being unpacked in that code — most likely the current path ignores it.

So right now: Blaster’s MDA implementation supports the wiring for intensity, but doesn’t use it in the framebuffer.
```

The M19 outputs the intensity bit on pin 6, I would like to retain this information. If I follow the MDA Buff will that give me the intensity bit?
`
Buff.setMDA32(Line - YBorder, BuffX - XBorderAdj, MDA8);`

jdelange, 2025-09-25:
What should the IPPRange be for the M19?

```
static std::pair<uint32_t, uint32_t> getIPPRange(TTL M) {
  switch (M) {
  case TTL::CGA:
  case TTL::EGA:
    return {4, 16};
  case TTL::MDA:
    return {5, 16};
  }
  std::cerr << "Bad Mode in getIPPRange(" << modeToStr(M) << ")\n";
  exit(1);
}
```

jdelange, 2025-09-25:
From the code below I understand that you do take the intensity at pin 26m but you only set the starting pin.
`
static constexpr const uint32_t MDA_VI_GPIO = 26; // 26-27:IV (Intensity,Video)`

So that's good, follwing this the M19 will also have the intensity processed.

scrapcomputing, 2025-09-29:
Yes, if you are not getting any output there must be something wrong with the code, possibly a crash.

You can debug by adding print statements , like `std::cout << "SOMETHING\n":`. These will show up in the debug terminal.

jdelange, 2025-10-04:
I have updated the code with an additional M19 profile. At for testing I cut the Buff filling at 350 lines to prevent overflow. The profile and timings are designed to accommodate the 640x400 profile. I have run multiple debug sessions. The code runs, but I can't get any output to the screen. In addition to loading your pre-compiled firmware, I have also compiled your unmodified code myself and flashed that. That works and gives the same output as shown above.

So:

1. I am able to compile, flash and run code successfully.
2. The test setup is wired correctly and running.
3. My modified code is running (no crash, no infinite loop)
4. When compiled in DEBUG mode I am able to see what is happening
5. I get no output to the screen due to a coding error somewhere, the debug provides no clue (to me)

Would it be an option that you take a look at what's going wrong? I would be more than happy to share my code.

Thanks, Jan

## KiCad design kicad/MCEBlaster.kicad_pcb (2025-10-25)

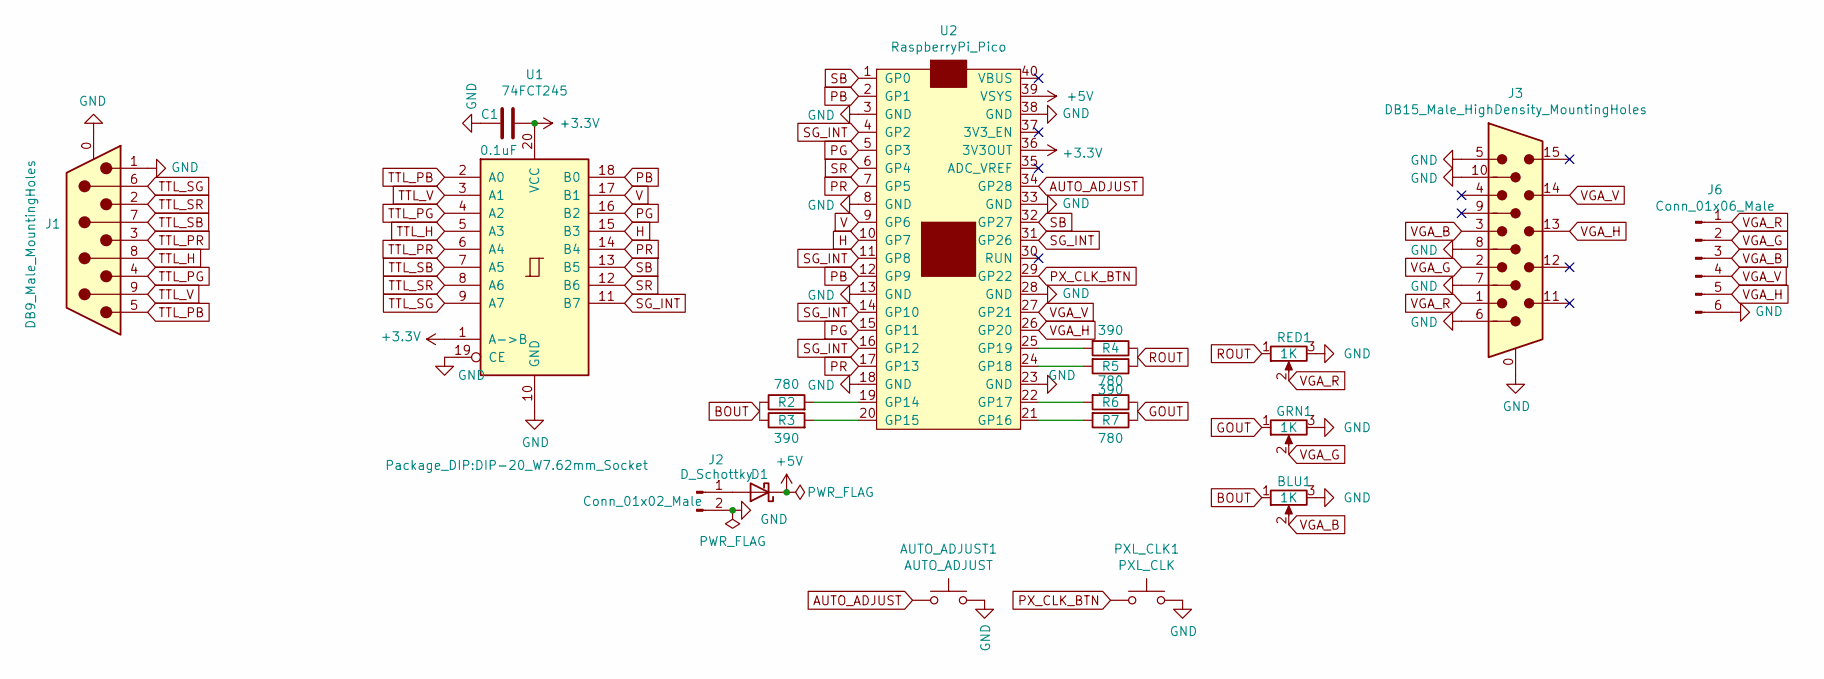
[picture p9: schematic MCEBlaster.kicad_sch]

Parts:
AUTO_ADJUST1: AUTO_ADJUST; SW_PUSH_6mm
BLU1: 1K; Potentiometer_Runtron_RM-065_Vertical
C1: 0.1uF; C_Disc_D4.3mm_W1.9mm_P5.00mm
D1: D_Schottky; D_A-405_P7.62mm_Horizontal
GRN1: 1K; Potentiometer_Runtron_RM-065_Vertical
J1: DB9_Male_MountingHoles; DSUB-9_Male_Horizontal_P2.77x2.84mm_EdgePinOffset4.94mm_Hou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
J2: Conn_01x02_Male; PinHeader_1x02_P2.54mm_Vertical
J3: DB15_Male_HighDensity_MountingHoles; VGA_connector_both_short_and_long
J6: Conn_01x06_Male; PinHeader_1x06_P2.54mm_Vertical
PXL_CLK1: PXL_CLK; SW_PUSH_6mm
R2, R5, R7: 780; R_Axial_DIN0207_L6.3mm_D2.5mm_P10.16mm_Horizontal
R3, R4, R6: 390; R_Axial_DIN0207_L6.3mm_D2.5mm_P10.16mm_Horizontal
RED1: 1K; Potentiometer_Runtron_RM-065_Vertical
U1: 74FCT245; DIP-20_W7.62mm_Socket
U2: RaspberryPi_Pico; raspberry_pi_pico

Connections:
+3V3: C1.1, U1.1 (A->B), U1.20 (VCC), U2.36 (3V3OUT)
+5V: D1.1 (K), U2.39 (VSYS)
AUTO_ADJUST: AUTO_ADJUST1.1, U2.34 (GP28)
BOUT: BLU1.1, R2.1, R3.1
GND: AUTO_ADJUST1.2, BLU1.3, C1.2, GRN1.3, J1.0 (PAD), J1.1, J2.2, J3.0, J3.5, J3.6, J3.7, J3.8, J3.10, J6.6, PXL_CLK1.2, RED1.3, U1.10 (GND), U1.19 (CE), U2.3 (GND), U2.8 (GND), U2.13 (GND), U2.18 (GND), U2.23 (GND), U2.28 (GND), U2.33 (GND), U2.38 (GND)
GOUT: GRN1.1, R6.1, R7.1
H: U1.15 (B3), U2.10 (GP7)
unnamed: D1.2 (A), J2.1
unnamed: R2.2, U2.19 (GP14)
unnamed: R3.2, U2.20 (GP15)
unnamed: R7.2, U2.21 (GP16)
unnamed: R6.2, U2.22 (GP17)
unnamed: R5.2, U2.24 (GP18)
unnamed: R4.2, U2.25 (GP19)
PB: U1.18 (B0), U2.2 (GP1), U2.12 (GP9)
PG: U1.16 (B2), U2.5 (GP3), U2.15 (GP11)
PR: U1.14 (B4), U2.7 (GP5), U2.17 (GP13)
PX_CLK_BTN: PXL_CLK1.1, U2.29 (GP22)
ROUT: R4.1, R5.1, RED1.1
SB: U1.13 (B5), U2.1 (GP0), U2.32 (GP27)
SG_INT: U1.11 (B7), U2.4 (GP2), U2.11 (GP8), U2.14 (GP10), U2.16 (GP12), U2.31 (GP26)
SR: U1.12 (B6), U2.6 (GP4)
TTL_H: J1.8, U1.5 (A3)
TTL_PB: J1.5, U1.2 (A0)
TTL_PG: J1.4, U1.4 (A2)
TTL_PR: J1.3, U1.6 (A4)
TTL_SB: J1.7, U1.7 (A5)
TTL_SG: J1.6, U1.9 (A7)
TTL_SR: J1.2, U1.8 (A6)
TTL_V: J1.9, U1.3 (A1)
V: U1.17 (B1), U2.9 (GP6)
VGA_B: BLU1.2, J3.3, J6.3
VGA_G: GRN1.2, J3.2, J6.2
VGA_H: J3.13, J6.5, U2.26 (GP20)
VGA_R: J3.1, J6.1, RED1.2
VGA_V: J3.14, J6.4, U2.27 (GP21)

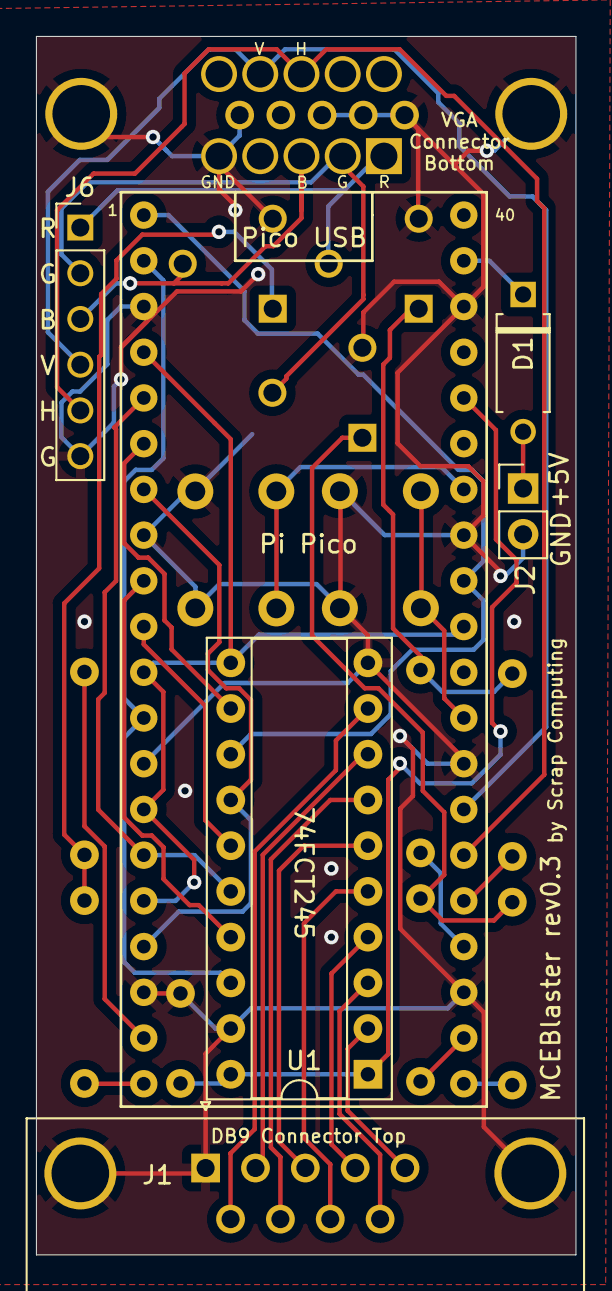
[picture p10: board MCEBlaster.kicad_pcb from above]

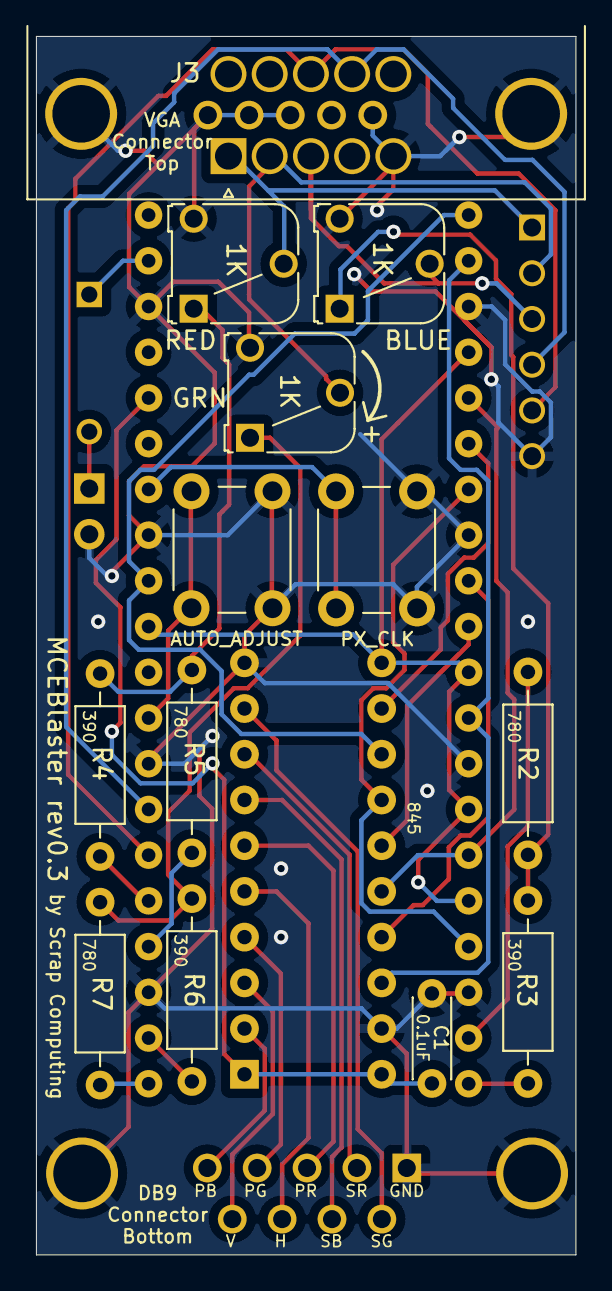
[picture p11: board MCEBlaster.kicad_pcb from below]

Board: 2 copper layers, 30.0 x 67.7 mm, 19 parts (13 on the bottom side), 36 nets.

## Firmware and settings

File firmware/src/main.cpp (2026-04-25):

//-*- C++ -*-
//
// Copyright (C) 2024 Scrap Computing
//

#include "Common.h"
#include "Debug.h"
#include "Flash.h"
#include "Pico.h"
#include "TTLReader.h"
#include "VGAWriter.h"

FlashStorage *Flash = nullptr;
Pico *Pi = nullptr;
PioProgramLoader *PPL = nullptr;

// Hack for linking error: undefined reference to `__dso_handle'
static void *__dso_handle = 0;

critical_section UnusedPIOLock;      // Used in VGAWriter.cpp

int main() {
  (void)__dso_handle;
  Pico Pico;
  Pi = &Pico;
  critical_section_init(&UnusedPIOLock);

  DBG_PRINT(sleep_ms(1500);)
  DBG_PRINT(std::cout << PROJECT_NAME << " rev." << REVISION_MAJOR << "."
                      << REVISION_MINOR << "\n";)
#ifndef PICO_WIRELESS
    // pico_w has no LED.
  Pico.initGPIO(PICO_DEFAULT_LED_PIN, GPIO_OUT, Pico::Pull::Down, "LED");
#endif
  Pico.initGPIO(AUTO_ADJUST_GPIO, GPIO_IN, Pico::Pull::Up, "AutoAdjust");
  // Note: pull up seems to help with level shifting
  Pico.initGPIO(PinRange(EGA_RGB_GPIO, EGA_RGB_GPIO + 6), GPIO_IN,
                Pico::Pull::Up, "EGA");
  Pico.initGPIO(PinRange(TTL_VSYNC_GPIO), GPIO_IN, Pico::Pull::Up, "TTL_VSync");
  Pico.initGPIO(PinRange(TTL_HSYNC_GPIO), GPIO_IN, Pico::Pull::Up, "TTL_HSync");
  Pico.initGPIO(PinRange(CGA_ACTUAL_RGB_GPIO, CGA_ACTUAL_RGB_GPIO + 6), GPIO_IN,
                Pico::Pull::Up, "CGA");
  Pico.initGPIO(PinRange(VGA_RGB_GPIO, VGA_RGB_GPIO + 6), GPIO_OUT,
                Pico::Pull::Down, "VGA");
  Pico.initGPIO(PinRange(MDA_VI_GPIO, MDA_VI_GPIO + 2), GPIO_IN, Pico::Pull::Up,
                "MDA");

  // Read Presets from flash.
  FlashStorage FlashMain;
  Flash = &FlashMain;
  PioProgramLoader PioLoader;
  PPL = &PioLoader;

  VGAWriter VGAW(Pico, *PPL);
  VGAW.runForEver();
  return 0;
}

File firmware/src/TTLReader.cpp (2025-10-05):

//-*- C++ -*-
//
// Copyright (C) 2024 Scrap Computing
//

#include "TTLReader.h"
#include "Common.h"
#include "DisplayBuffer.h"
#include "Utils.h"
#include "pico/stdlib.h"
#include <cmath>

static constexpr const uint32_t EGABorderCounter = 700;
static constexpr const uint32_t CGABorderCounter = 700;
static constexpr const uint32_t MDABorderCounter = 800;

static inline void EGA640x350PioConfig(PIO Pio, uint SM, uint Offset,
                                       uint RGB_GPIO, uint32_t HSYNC_GPIO,
                                       uint16_t ClkDivInt, uint8_t ClkDivFrac,
                                       uint32_t InstrDelay,
                                       uint32_t SamplingOffset,
                                       Polarity HSyncPolarity) {
  auto GetSmConfig = [Offset](uint32_t InstrDelay, uint32_t SamplingOffset,
                              Polarity HSyncPolarity) {
    switch (HSyncPolarity) {
    case Polarity::Pos: {
#include "EGASwitchCase_PosHSync_config_cpp"
      break;
    }
    case Polarity::Neg: {
#include "EGASwitchCase_NegHSync_config_cpp"
      break;
    }
    }
    std::cerr << "Bad InstrDelay or SamplingOffset in EGA: GetSmConfig("
              << InstrDelay << ", " << SamplingOffset << ")\n";
    exit(1);
  };
  pio_sm_config Conf = GetSmConfig(InstrDelay, SamplingOffset, HSyncPolarity);

  // in pins: RGB
  sm_config_set_in_pins(&Conf, RGB_GPIO);
  // Shift to the right, no auto-push
  sm_config_set_in_shift(&Conf, /*shift_right=*/true, /*autopush=*/false,
                         /*push_threshold=*/32);
  // We only need an input fifo, so create a 8-entry queue.
  sm_config_set_fifo_join(&Conf, PIO_FIFO_JOIN_RX);
  // Set the clock divider
  sm_config_set_clkdiv_int_frac(&Conf, ClkDivInt, ClkDivFrac);

  sm_config_set_jmp_pin(&Conf, HSYNC_GPIO);
  // Initializations
  // Set pin direction
  pio_sm_set_consecutive_pindirs(Pio, SM, RGB_GPIO, 8, /*is_out=*/false);

  pio_sm_init(Pio, SM, Offset, &Conf);
}

static inline void CGA640x200PioConfig(PIO Pio, uint SM, uint Offset,
                                       uint RGB_GPIO, uint32_t HSYNC_GPIO,
                                       uint16_t ClkDivInt, uint8_t ClkDivFrac,
                                       uint32_t InstrDelay,
                                       uint32_t SamplingOffset,
                                       Polarity HSyncPolarity) {
  auto GetSmConfig = [Offset](uint32_t InstrDelay, uint32_t SamplingOffset,
                              Polarity HSyncPolarity) {
    switch (HSyncPolarity) {
    case Polarity::Pos: {
#include "CGASwitchCase_PosHSync_config_cpp"
      break;
    }
    case Polarity::Neg: {
#include "CGASwitchCase_NegHSync_config_cpp"
    }
    }
    std::cerr << "Bad InstrDelay or SamplingOffset in CGA: GetSmConfig("
              << InstrDelay << ", " << SamplingOffset << ")\n";
    exit(1);
  };
  pio_sm_config Conf = GetSmConfig(InstrDelay, SamplingOffset, HSyncPolarity);
  // in pins: RGB
  sm_config_set_in_pins(&Conf, RGB_GPIO);
  // Shift to the right, no auto-push
  // This means that if we IN from Pins == 0b0011, then ISR = 0b00...0011
  sm_config_set_in_shift(&Conf, /*shift_right=*/true, /*autopush=*/false,
                         /*push_threshold=*/32);

  // Out: Shift Right
  sm_config_set_out_shift(&Conf, /*shift_right=*/true, /*autopush=*/false,
                          /*push_threshold=*/32);

  sm_config_set_jmp_pin(&Conf, HSYNC_GPIO);

  // We only need an input fifo, so create a 8-entry queue.
  sm_config_set_fifo_join(&Conf, PIO_FIFO_JOIN_RX);

  // Set the clock divider
  sm_config_set_clkdiv_int_frac(&Conf, ClkDivInt, ClkDivFrac);

  // Initializations
  // Set pin direction
  pio_sm_set_consecutive_pindirs(Pio, SM, RGB_GPIO, 8, /*is_out=*/false);

  pio_sm_init(Pio, SM, Offset, &Conf);
}

static inline void MDA720x350PioConfig(PIO Pio, uint SM, uint Offset,
                                       uint MDA_GPIO, uint HSYNC_GPIO,
                                       uint16_t ClkDivInt, uint8_t ClkDivFrac,
                                       uint32_t InstrDelay,
                                       uint32_t SamplingOffset,
                                       Polarity HSyncPolarity) {
  auto GetSmConfig = [Offset](uint32_t InstrDelay, uint32_t SamplingOffset, Polarity HSyncPolarity) {
    switch (HSyncPolarity) {
    case Polarity::Pos: {
#include "MDASwitchCase_PosHSync_config_cpp"
      break;
    }
    case Polarity::Neg: {
#include "MDASwitchCase_NegHSync_config_cpp"
      break;
    }
    }
    std::cerr << "Bad InstrDelay or SamplingOffset in MDA: GetSmConfig("
              << InstrDelay << ", " << SamplingOffset << ")\n";
    exit(1);
  };
  pio_sm_config Conf = GetSmConfig(InstrDelay, SamplingOffset, HSyncPolarity);
  // in pins: VI (Video, Intensity)
  sm_config_set_in_pins(&Conf, MDA_GPIO);
  // Shift to the right, no auto-push
  sm_config_set_in_shift(&Conf, /*shift_right=*/true, /*autopush=*/false,
                         /*push_threshold=*/32);
  sm_config_set_jmp_pin(&Conf, HSYNC_GPIO);

  // We only need an input fifo, so create a 8-entry queue.
  sm_config_set_fifo_join(&Conf, PIO_FIFO_JOIN_RX);

  // Set the clock divider
  sm_config_set_clkdiv_int_frac(&Conf, ClkDivInt, ClkDivFrac);

  // Initializations
  // Set pin direction
  pio_sm_set_consecutive_pindirs(Pio, SM, MDA_GPIO, 2, /*is_out=*/false);
  pio_sm_set_consecutive_pindirs(Pio, SM, HSYNC_GPIO, 1, /*is_out=*/false);

  pio_sm_init(Pio, SM, Offset, &Conf);
}

void AutoAdjustBorder::resetBorders() {
  TmpXBorder = XBorderInit;
  TmpYBorder = YBorderInit;
}

void AutoAdjustBorder::applyBorders(const TTLDescr &TimingsTTL) {
  // Clear screen if borders have changed to avoid artifacts.
  if (XBorder != TmpXBorder || YBorder != TmpYBorder)
    TTLR.getBuff().clear();

  // Update TTLReader's values.
  XBorder = TmpXBorder;
  YBorder = TmpYBorder;

  switch (TimingsTTL.Mode) {
  case TTL::CGA:
  case TTL::EGA:
    if (TTLReader::isHighRes(TimingsTTL))
      EGABorderOpt = BorderXY(XBorder, YBorder);
    else
      CGABorderOpt = BorderXY(XBorder, YBorder);
    break;
  case TTL::MDA:
    // We have enough frame-buffer size to not have to worry about the beginning
    // of the visible pixels (due to 2-pixels per byte scheme) so just use an
    // XBorder of 0.
    XBorder = 0;
    MDABorderOpt = BorderXY(XBorder, YBorder);
    break;
  }
}

void AutoAdjustBorder::setBorder(const BorderXY &XY) {
  if (ManualTTLEnabled && !XBorderAUTO)
    XBorder = ManualTTL.H_BackPorch;
  else
    XBorder = XY.X;

  if (ManualTTLEnabled && !YBorderAUTO)
    YBorder = ManualTTL.V_BackPorch;
  else
    YBorder = XY.Y;
}

void AutoAdjustBorder::forceStart() {
  if (Enabled == State::Off)
    Enabled = State::SingleON;
  FrameCnt = 0u;
  StartFrame = FrameCnt + AUTO_ADJUST_START_AFTER;
  StopFrame = FrameCnt + AUTO_ADJUST_DURATION;
}
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

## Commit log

2024-06-28 Rev 0.1
    [MCEBlaster.kicad_pcb, MCEBlaster.sch]
2024-06-29 README: Add schematic
2024-06-29 Fixed BOM IC part number to the correct 74LVC245
    [MCEBlaster.sch]
2024-06-30 Adds Through-hole PCB
    [MCEBlaster.kicad_pcb, MCEBlaster.sch]
2024-11-09 THT pcb updates
    [MCEBlaster.kicad_pcb]
2025-04-23 README: Add VGA connector part number in BOM (thanks @wrljet)
2025-05-31 Rev 0.2 beta: Major redesign and new features like Manual TTL
    - Auto-detect horizontal and vertical sync
    - Manual-TTL menu
    - Info TTL menu
    - On-screen menus no longer freeze the screen
    - Support VGA 640x480 and 640x400 for non-standard MDA
    - Reset to factory defaults
    [Common.h, DisplayBuffer.h]
2025-06-23 Rev 0.3: Adds sampling offset for better sampling
    Other changes:
    - ManualTTL allow negative X Y offsets
    - Fixes MDA image centering
    [Common.h, DisplayBuffer.h, TTLReader.cpp]
2025-06-24 Increase MDA pixels by 32 more pixels and disable XBorder to fix horizontal offset issues
    [TTLReader.cpp]
2025-06-29 Fix reading offsets from flash
    [TTLReader.cpp]
2025-07-13 Remove ADC and change cmake include path to fix missing hardware/flash.h build issue
    [Pico.cpp]
2025-08-05 Pico 2 build
2025-09-11 Fix porch sizes which caused incorrect colors in some monitors
    Many thanks to @Bs0Dd for not only reporting the issue but also finding the root cause!
    [VGAWriter.cpp]
2025-09-14 Several bug fixes and improvements
    - Fix MDA display bug introduced in v0.3 beta 7
    - Fix MDA pixel clipping by making the MDA buffer even larger
    - Fix VGA sync pixels
    - Character bitmaps improvements
    - Fix mode switching bug from EGA 640x200 to 640x350
    - Fix vertical centering of EGA 640x350
    - Fix Manual-TTL menu long-click bug
    - Pico2 now has a wider buffer which should help fix pixel cropping in EGA 640x350
    [TTLReader.cpp, TTLReader.h, Timings.h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]
2025-09-17 Rework the SamplingOffsetMod code
    [TTLReader.cpp]
2025-09-19 Finally fix EGA 640x350 horizontal clipping
    [Timings.h]
2025-09-29 Replace std::vector with std::array in HorizMenu
    [DisplayBuffer.h, TTLReader.h]
2025-09-29 Replace std::vector with FixedVector
    [TTLReader.h]
2025-10-01 Replace std::string with Utils::StaticString in HorizMenu
    [DisplayBuffer.h, TTLReader.cpp]
2025-10-05 Replace splash image with smaller to save memory (pico 1 only), performance tweaking, and +2 CGA sampling offsets
    [TTLReader.cpp]
2025-10-05 Bug fix: med-push auto-adjust will now enter auto-adjust
    Thanks to @Bs0Dd for reporting the bug!
    [TTLReader.cpp]
2025-10-25 PCB rev0.2
    [MCEBlaster.kicad_pcb, MCEBlaster.kicad_sch, MCEBlaster.sch]
2025-10-25 PCB Rev 0.3
    Updates the VGA connector footprint. Should accept both "short" and "long" connectors.
    [MCEBlaster.kicad_pcb, MCEBlaster.kicad_sch]
2026-03-16 Turn off VGA after 30s to avoid CRT burn-in
    Stop displaying the "No Signal" message after 30s and turn off the signals
    that drive the VGA. Some later CRT models should also enter low-power mode.
    [Common.h, VGAWriter.cpp]
2026-04-26 Turn on the VGA signal when the user pushes a button
    When there is no TTL signal we turn off the VGA signal to save CRTs.
    If the user pushes a button we turn it back on again.
